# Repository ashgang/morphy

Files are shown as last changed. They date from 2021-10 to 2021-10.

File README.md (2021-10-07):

# Morphy
Contains the morphy design files and sources codes. The Hardware folder contains the schematics of various versions of the Morphy board and the associated evaluation board. The Software folder consists of the MorphyCore subfolder which contains the core morphy functionality, and the reference implementation of the client library for FreeRTOS.

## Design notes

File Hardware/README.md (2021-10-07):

# Morphy Hardware
MorphyPP3_board folder contains the design files for the Morphy PP3 form factor design.
MorphyDev_Board folder contains the design files of the development board for Morphy.

[All design documents including Board Schematics, PCB design and BOM sheets ]

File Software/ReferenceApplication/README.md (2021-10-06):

# Reference Application
This subfolder contains reference implementation of the morphy extension to FreeRTOS, the reference client library implementation is included within the freertos folder. An application example developed for Nordic nRF52840-DK board is included and the application was developed on Nordic SDK version: nRF5_SDK_17.0.2.

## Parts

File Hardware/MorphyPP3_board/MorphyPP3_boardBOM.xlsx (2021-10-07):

Comment | Description | Designator | Footprint | LibRef | Quantity
0.1uF | 0.1碌F ceramic capacitors A capacitor is a passive two-terminal electrical component used to store electrical energy temporarily in an electric field. | C1, C2, C3, C4 | 0603 | 0.1UF-0603-25V-5% | 4
C-USC0402 | CAPACITOR, American symbol | C5, C6 | C0402 | C-USC0402 | 2
FIDUCIAL1X2 | Fiducial Alignment Points Point-of-reference for pick-and-place machines and other optical instruments. | FD1, FD2, FD3, FD4 | FIDUCIAL-1X2 | FIDUCIAL1X2 | 4
AMPHENOL-BERGSTAK®-10POSPLUG | Amphenol鈥檚 BergStak庐 0.5mm is a comprehensive and versatile board-to-board solution designed for reliable and high-density applications. The unique design of scoop-proof housing ensures terminals are not damaged during mating. | J1 | 10132797-10POS-PLUG | AMPHENOL-BERGSTAK®-10POSPLUG | 1
CONN_06NO_SILK_NO_POP | Multi connection point. Often used as Generic Header-pin footprint for 0.1 inch spaced/style header connections On any of the 0.1 inch spaced packages, you can populate with these: Break Away Headers - Straight (PRT-00116) Break Away Male Headers - Right Angle (PRT-00553) Female Headers (PRT-00115) Break Away Headers - Machine Pin (PRT-00117) Break Away Female Headers - Swiss Machine Pin (PRT-00743) Arduino Stackable Header - 6 Pin (PRT-09280) For SCREWTERMINALS and SPRING TERMINALS visit here: Screw Terimnals on SparkFun.com (5mm/3.5mm/2.54mm spacing) This device is also useful as a general connection point to wire up your design to another part of your project. Our various solder wires solder well into these plated through hole pads. Hook-Up Wire - Assortment (Stranded, 22 AWG) (PRT-11375) Hook-Up Wire - Assortment (Solid Core, 22 AWG) (PRT-11367) View the entire wire category on our website here | J2 | 1X06_NO_SILK | CONN_06NO_SILK_NO_POP | 1
IIOT |  | LOGO1, LOGO2 | IIOT | IIOT | 2
PIC18(L)F65/66K40MR | 64-Pin, Low-Power, High-Performance Microcontrollers with XLP Technology | MCU1 | QFN50P900X900X100-65T715N | PIC18(L)F65/66K40MR | 1
310mA/60V/1.6Ω | N-channel MOSFETs Voltage controlled devices that allow control of high current outputs. SparkFun Products: | Q1, Q2 | SOT323 | MOSFET-NCH-2N7002PW | 2
R-EU_R0402 | RESISTOR, European symbol | R1, R2, R3, R4, R5, R6 | R0402 | R-EU_R0402 | 6
R-US_R0805 | RESISTOR, American symbol | R7 | R0805 | R-US_R0805 | 1
AB1805 |  | RTC1 | QFN-16-3X3 | AB1805 | 1
PM-5R0H/V104-R-VER | CAP 100MF -20% +80% 5V T/H | SC1, SC2, SC3, SC4, SC5, SC6, SC7, SC8, SC9, SC10, SC11, SC12, SC13, SC14, SC15, SC16 | EATON-13X11.3X6-V | PM-5R0H/V104-R-VER | 16
TEST-POINT3X4 | SparkFun Test Points Bare copper test points for troubleshooting or In-Circuit-Testing. These are used by our Production team for verifying production board runs using pogo-pins on test beds. SparkFun Products: SparkFun Load Cell Amplifier | TP1, TP2, TP3 | PAD.03X.04 | TEST-POINT3X4 | 3
ADG824 | 0.5 鈩?CMOS 1.65 V to 3.6 V Dual SPDT/2:1 Mux in Mini LFCSP Package | U1, U2, U3, U4, U5, U6, U7, U8, U9, U10, U11, U12, U13, U14, U15, U16, U17 | CP-10-10 | ADG824 | 17

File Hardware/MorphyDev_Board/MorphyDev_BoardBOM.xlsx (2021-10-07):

Comment | Description | Designator | Footprint | LibRef | Quantity
BAT-1CELLKEYSTONE-1058 |  | BAT1 | KEYSTONE-1058 | BAT-1CELLKEYSTONE-1058 | 1
0.1uF | CAPACITOR, American symbol | C1, C2, C3, C4 | C0603 | C-USC0603 | 4
C-USC0603 | CAPACITOR, American symbol | C5, C6 | C0603 | C-USC0603 | 2
CONN_02 | Multi connection point. Often used as Generic Header-pin footprint for 0.1 inch spaced/style header connections On any of the 0.1 inch spaced packages, you can populate with these: Break Away Headers - Straight (PRT-00116) Break Away Male Headers - Right Angle (PRT-00553) Female Headers (PRT-00115) Break Away Headers - Machine Pin (PRT-00117) Break Away Female Headers - Swiss Machine Pin (PRT-00743) For SCREWTERMINALS and SPRING TERMINALS visit here: Screw Terimnals on SparkFun.com (5mm/3.5mm/2.54mm spacing) This device is also useful as a general connection point to wire up your design to another part of your project. Our various solder wires solder well into these plated through hole pads. Hook-Up Wire - Assortment (Stranded, 22 AWG) (PRT-11375) Hook-Up Wire - Assortment (Solid Core, 22 AWG) (PRT-11367) View the entire wire category on our website here Special notes: Molex polarized connector foot print use with: PRT-08233 with associated crimp pins and housings. 2.54_SCREWTERM for use with PRT-10571. 3.5mm Screw Terminal footprints for PRT-08084 5mm Screw Terminal footprints for use with PRT-08432 | J1 | 1X02 | CONN_02 | 1
CONN_06NO_SILK_NO_POP | Multi connection point. Often used as Generic Header-pin footprint for 0.1 inch spaced/style header connections On any of the 0.1 inch spaced packages, you can populate with these: Break Away Headers - Straight (PRT-00116) Break Away Male Headers - Right Angle (PRT-00553) Female Headers (PRT-00115) Break Away Headers - Machine Pin (PRT-00117) Break Away Female Headers - Swiss Machine Pin (PRT-00743) Arduino Stackable Header - 6 Pin (PRT-09280) For SCREWTERMINALS and SPRING TERMINALS visit here: Screw Terimnals on SparkFun.com (5mm/3.5mm/2.54mm spacing) This device is also useful as a general connection point to wire up your design to another part of your project. Our various solder wires solder well into these plated through hole pads. Hook-Up Wire - Assortment (Stranded, 22 AWG) (PRT-11375) Hook-Up Wire - Assortment (Solid Core, 22 AWG) (PRT-11367) View the entire wire category on our website here | J2 | 1X06_NO_SILK | CONN_06NO_SILK_NO_POP | 1
CONN_025MM | Multi connection point. Often used as Generic Header-pin footprint for 0.1 inch spaced/style header connections On any of the 0.1 inch spaced packages, you can populate with these: Break Away Headers - Straight (PRT-00116) Break Away Male Headers - Right Angle (PRT-00553) Female Headers (PRT-00115) Break Away Headers - Machine Pin (PRT-00117) Break Away Female Headers - Swiss Machine Pin (PRT-00743) For SCREWTERMINALS and SPRING TERMINALS visit here: Screw Terimnals on SparkFun.com (5mm/3.5mm/2.54mm spacing) This device is also useful as a general connection point to wire up your design to another part of your project. Our various solder wires solder well into these plated through hole pads. Hook-Up Wire - Assortment (Stranded, 22 AWG) (PRT-11375) Hook-Up Wire - Assortment (Solid Core, 22 AWG) (PRT-11367) View the entire wire category on our website here Special notes: Molex polarized connector foot print use with: PRT-08233 with associated crimp pins and housings. 2.54_SCREWTERM for use with PRT-10571. 3.5mm Screw Terminal footprints for PRT-08084 5mm Screw Terminal footprints for use with PRT-08432 | J3, J4 | SCREWTERMINAL-5MM-2 | CONN_025MM | 2
CONN_03 | Multi connection point. Often used as Generic Header-pin footprint for 0.1 inch spaced/style header connections On any of the 0.1 inch spaced packages, you can populate with these: Break Away Headers - Straight (PRT-00116) Break Away Male Headers - Right Angle (PRT-00553) Female Headers (PRT-00115) Break Away Headers - Machine Pin (PRT-00117) Break Away Female Headers - Swiss Machine Pin (PRT-00743) Stackable Header - 3 Pin (Female, 0.1") (PRT-13875) For SCREWTERMINALS and SPRING TERMINALS visit here: Screw Terimnals on SparkFun.com (5mm/3.5mm/2.54mm spacing) This device is also useful as a general connection point to wire up your design to another part of your project. Our various solder wires solder well into these plated through hole pads. Hook-Up Wire - Assortment (Stranded, 22 AWG) (PRT-11375) Hook-Up Wire - Assortment (Solid Core, 22 AWG) (PRT-11367) View the entire wire category on our website here Special notes: Molex polarized connector foot print use with SKU : PRT-08232 with associated crimp pins and housings. | J5 | 1X03 | CONN_03 | 1
PIC18(L)F65/66K40PT | 64-Pin, Low-Power, High-Performance Microcontrollers with XLP Technology | MCU1 | QFP50P1200X1200X120-64N | PIC18(L)F65/66K40PT | 1
310mA/60V/1.6Ω | N-channel MOSFETs Voltage controlled devices that allow control of high current outputs. SparkFun Products: | Q1, Q2 | SOT323 | MOSFET-NCH-2N7002PW | 2
R-US_R0603 | RESISTOR, American symbol | R1, R2, R3, R4, R5, R6, R8, R9 | R0603 | R-US_R0603 | 8
R-US_R0805 | RESISTOR, American symbol | R7 | R0805 | R-US_R0805 | 1
AB1805 |  | RTC1 | QFN-16-3X3 | AB1805 | 1
PM-5R0H/V104-R-VER | CAP 100MF -20% +80% 5V T/H | SC1, SC2, SC3, SC4, SC5, SC6, SC7, SC8, SC9, SC10, SC11, SC12, SC13, SC14, SC15, SC16 | EATON-13X11.3X6-V | PM-5R0H/V104-R-VER | 16
TEST-POINT3X4 | SparkFun Test Points Bare copper test points for troubleshooting or In-Circuit-Testing. These are used by our Production team for verifying production board runs using pogo-pins on test beds. SparkFun Products: SparkFun Load Cell Amplifier | TP1, TP3 | PAD.03X.04 | TEST-POINT3X4 | 2
DG2535EDQ | IC ANALOG SWITCH DUAL | U1, U2, U3, U4, U5, U6, U7, U8, U9, U10, U11, U12, U13, U14, U15, U16, U17 | SOP50P490X110-10N | DG2535EDQ | 17

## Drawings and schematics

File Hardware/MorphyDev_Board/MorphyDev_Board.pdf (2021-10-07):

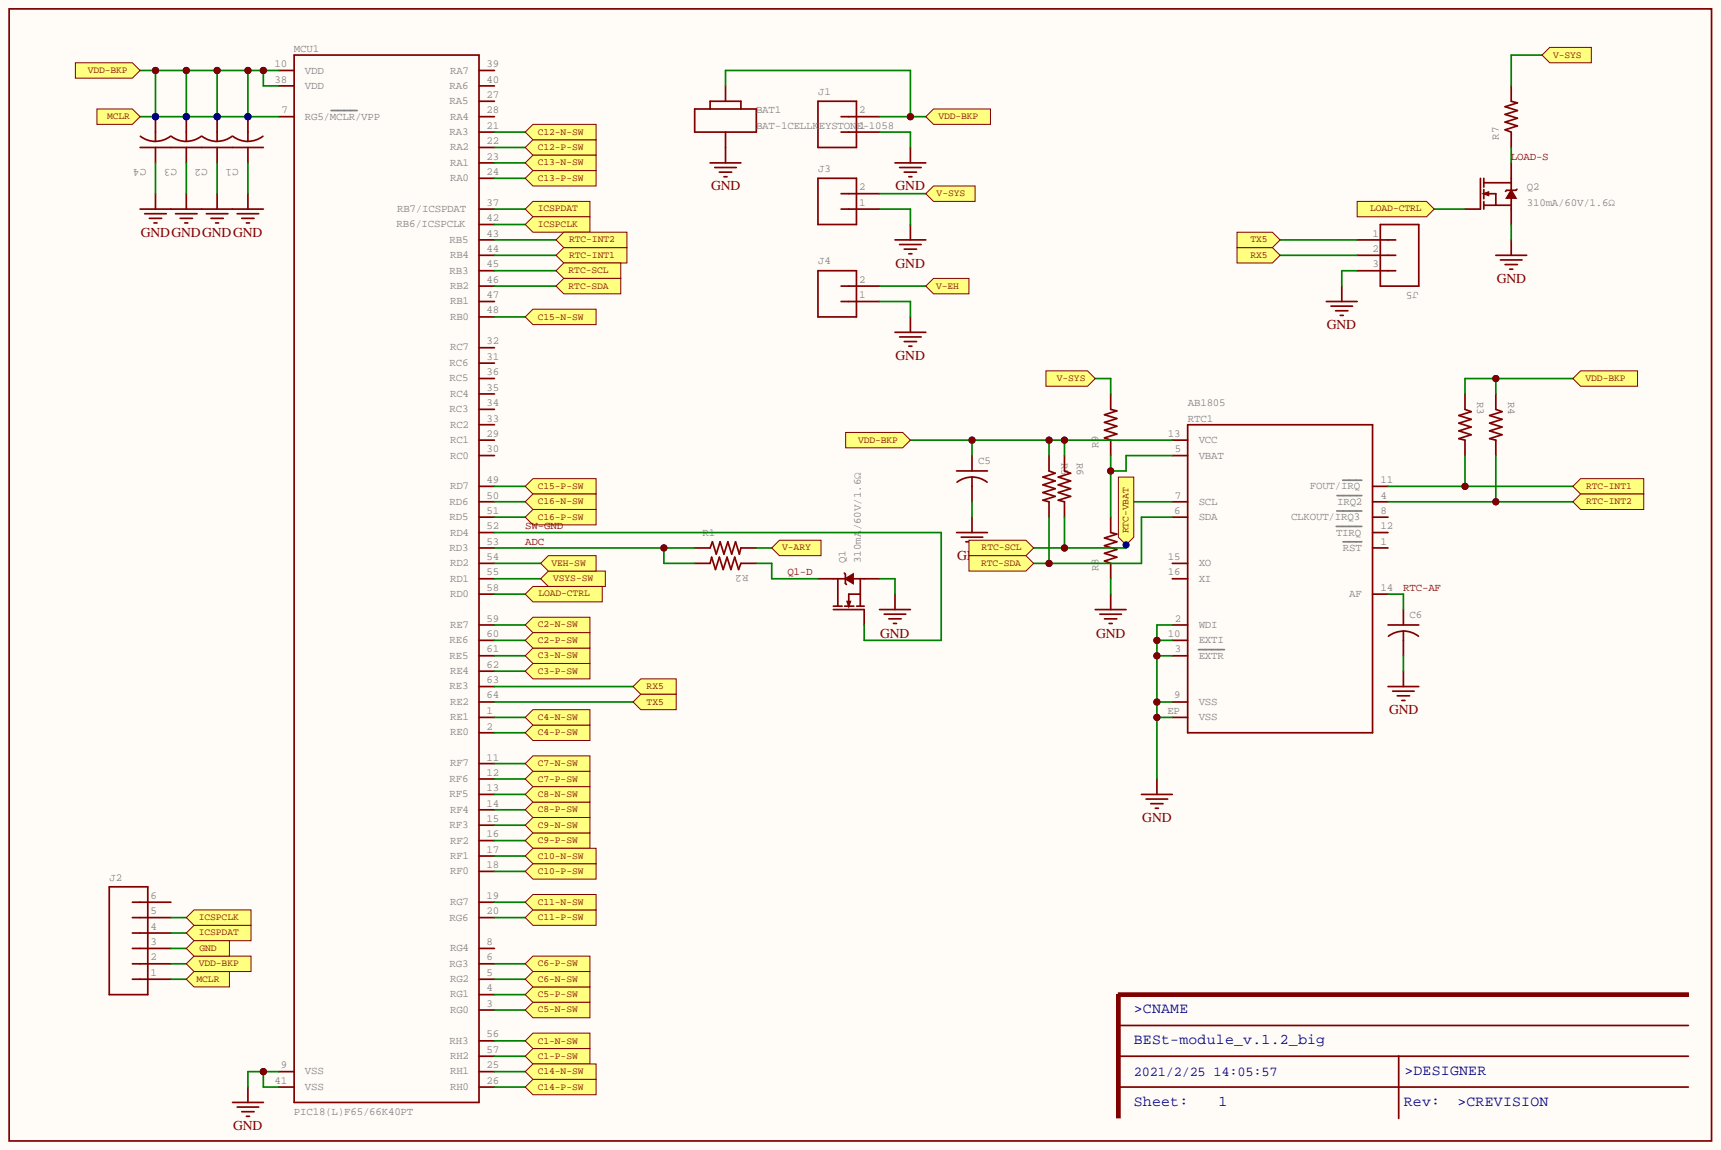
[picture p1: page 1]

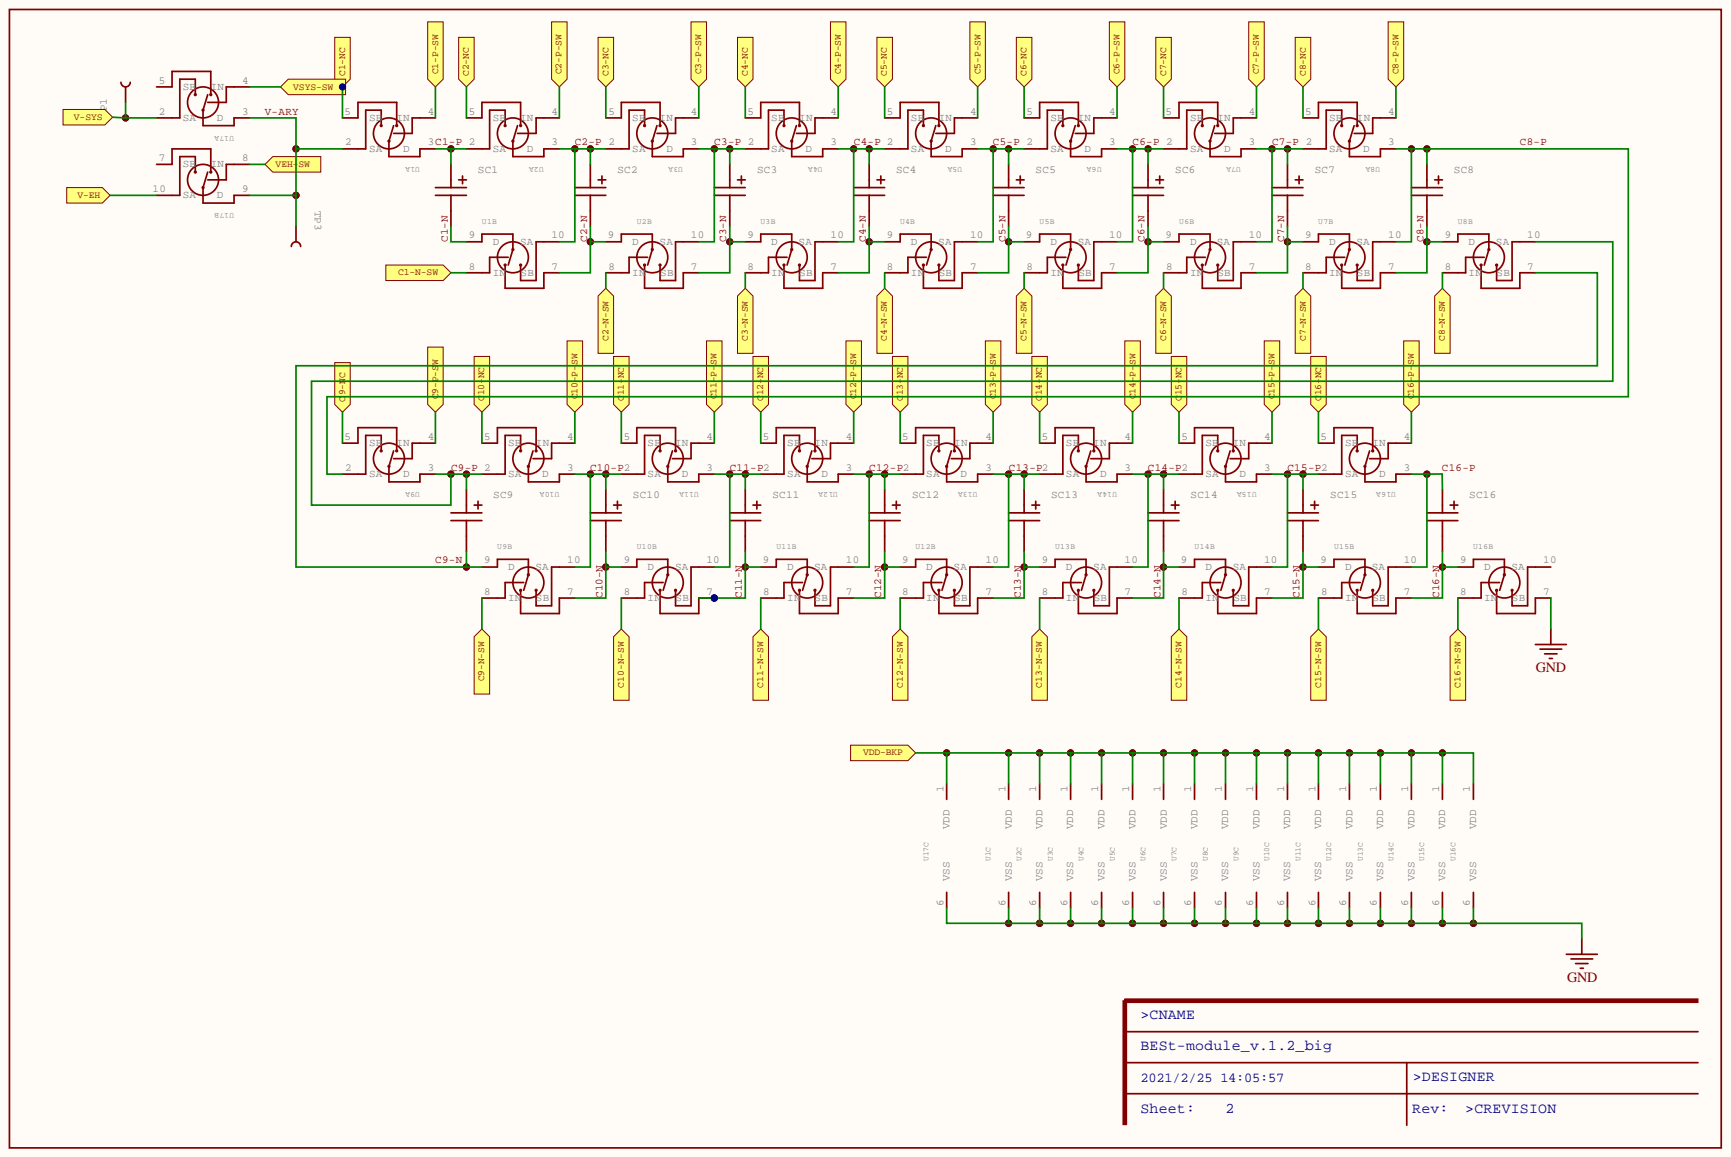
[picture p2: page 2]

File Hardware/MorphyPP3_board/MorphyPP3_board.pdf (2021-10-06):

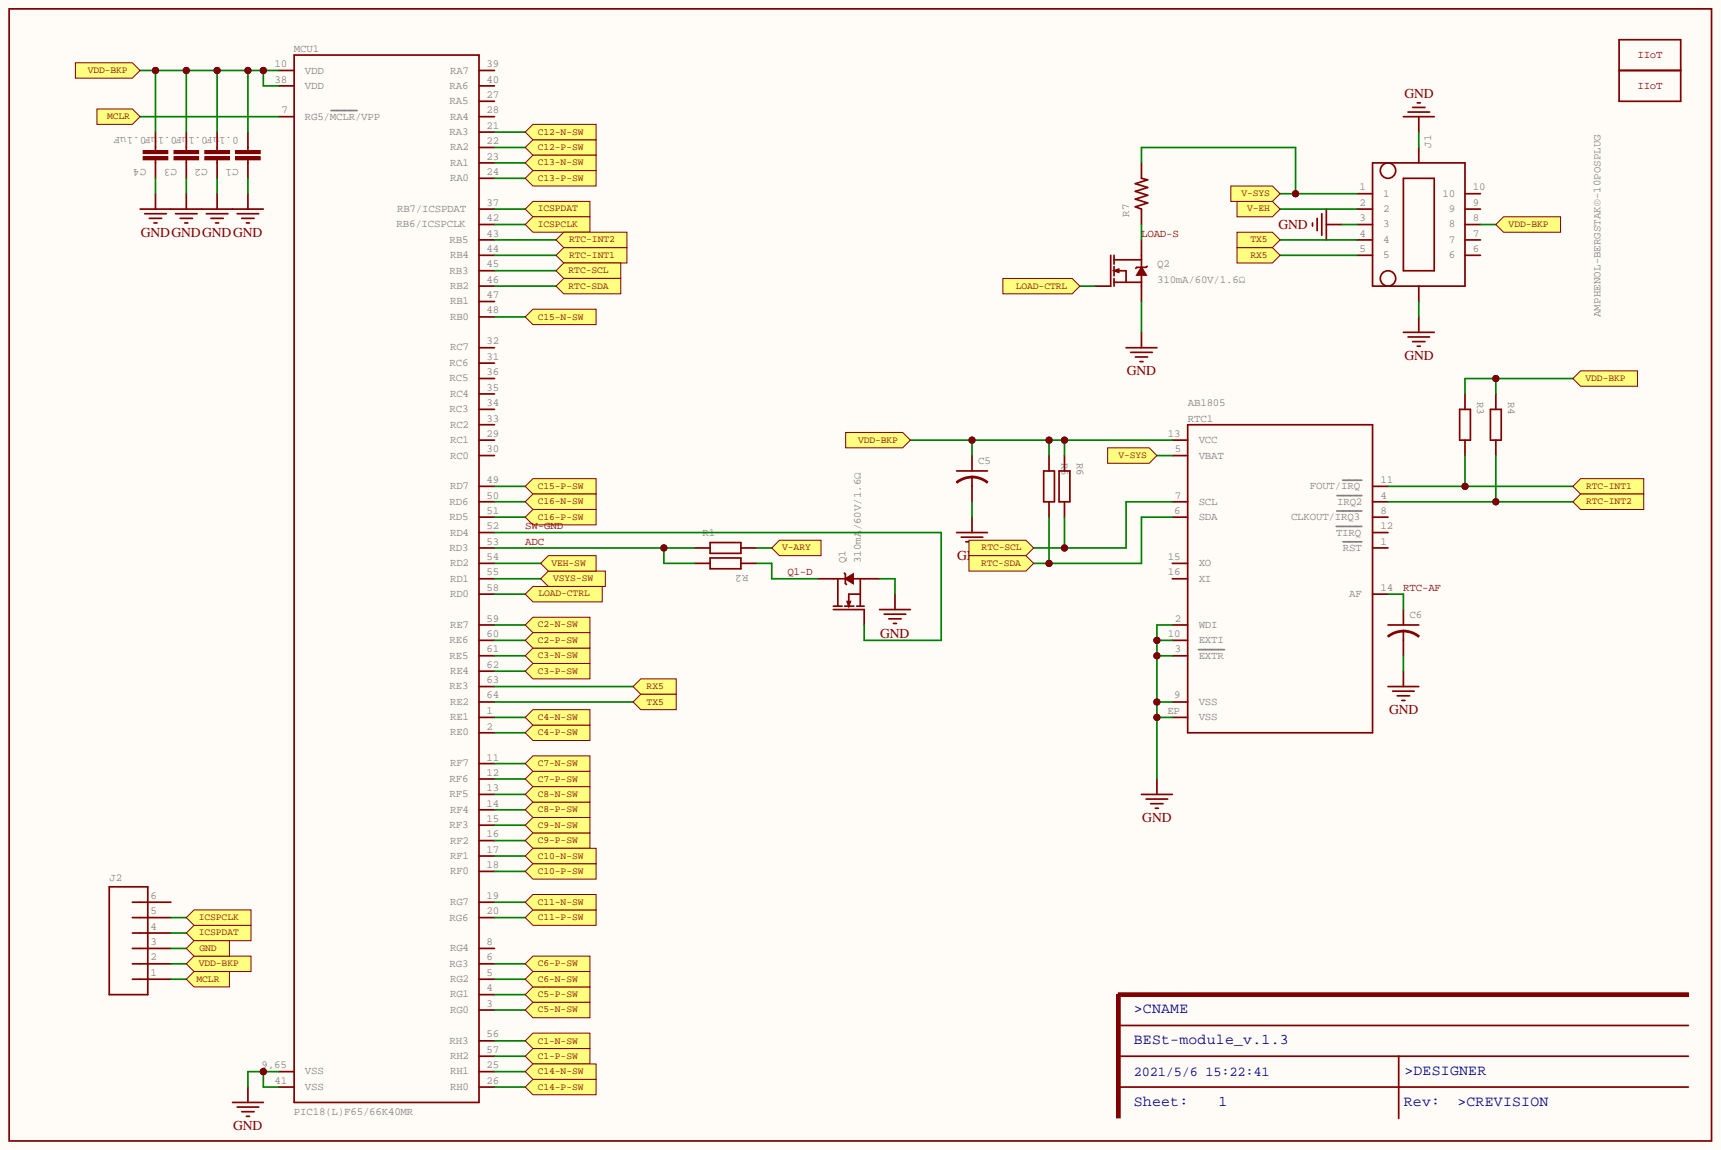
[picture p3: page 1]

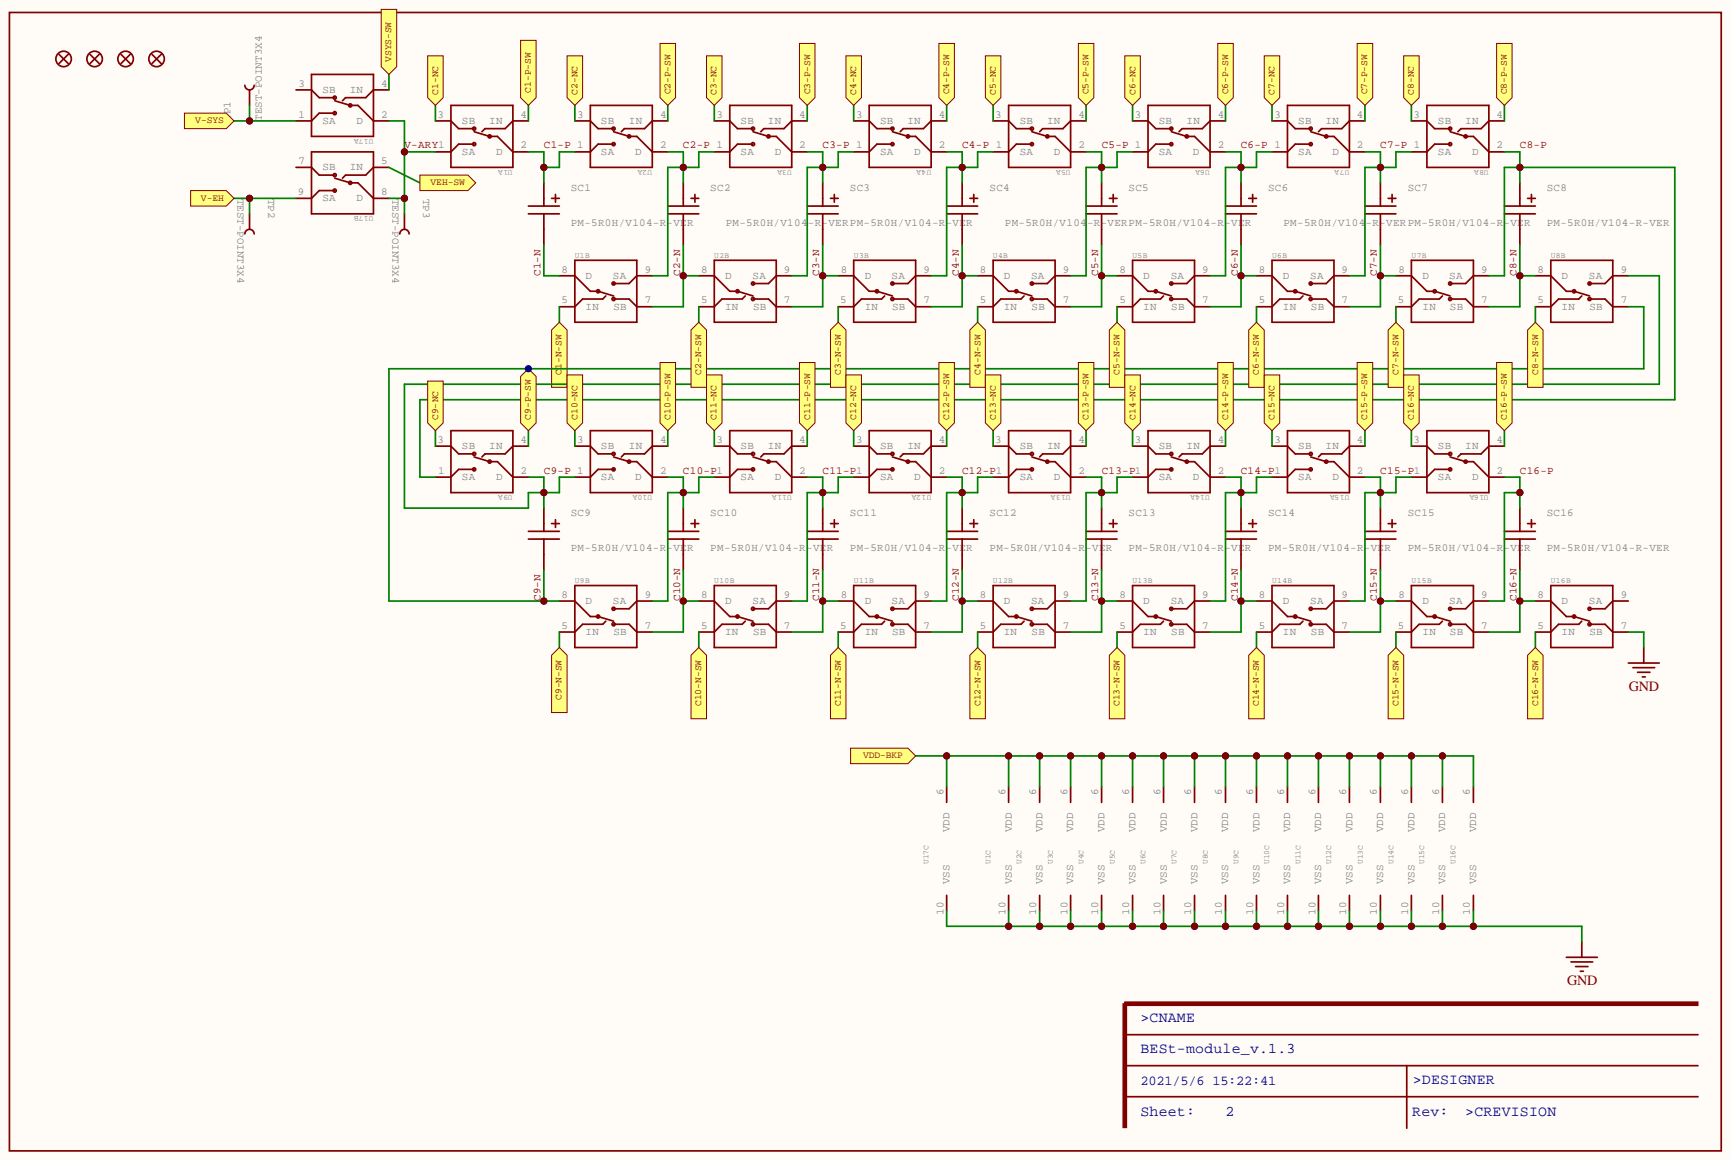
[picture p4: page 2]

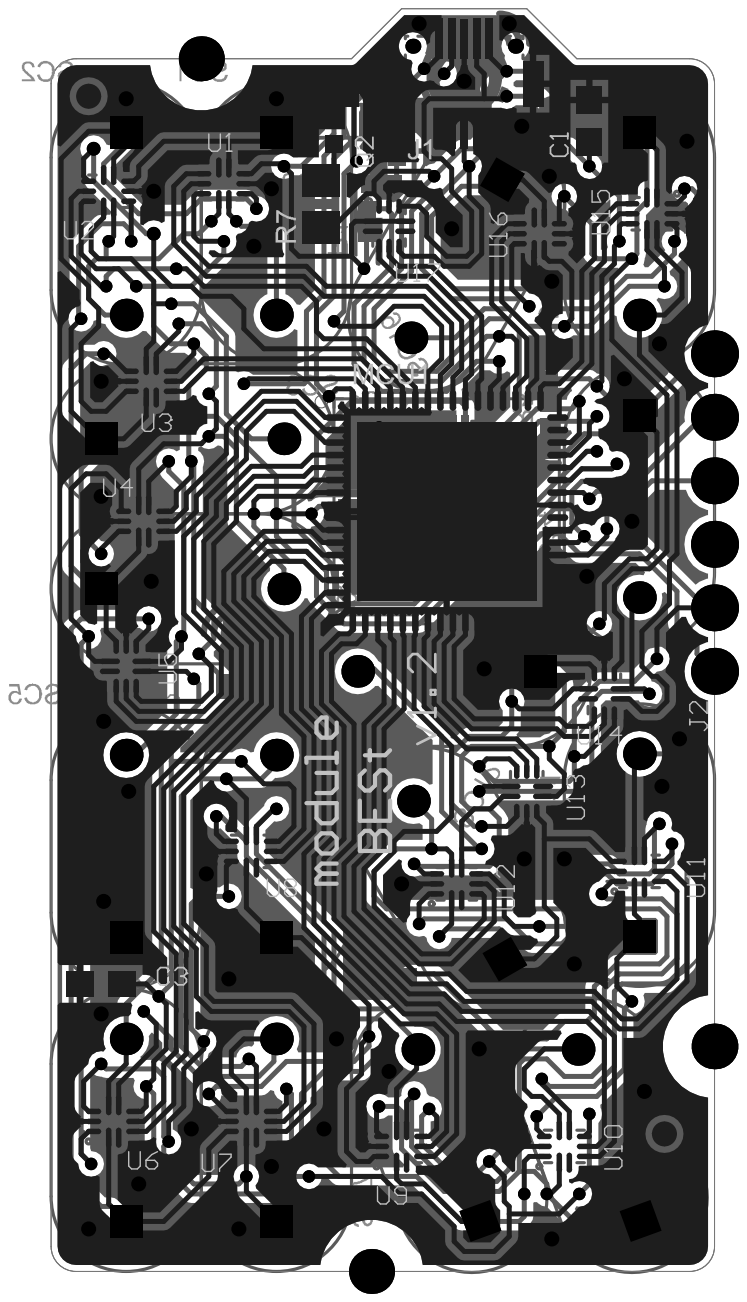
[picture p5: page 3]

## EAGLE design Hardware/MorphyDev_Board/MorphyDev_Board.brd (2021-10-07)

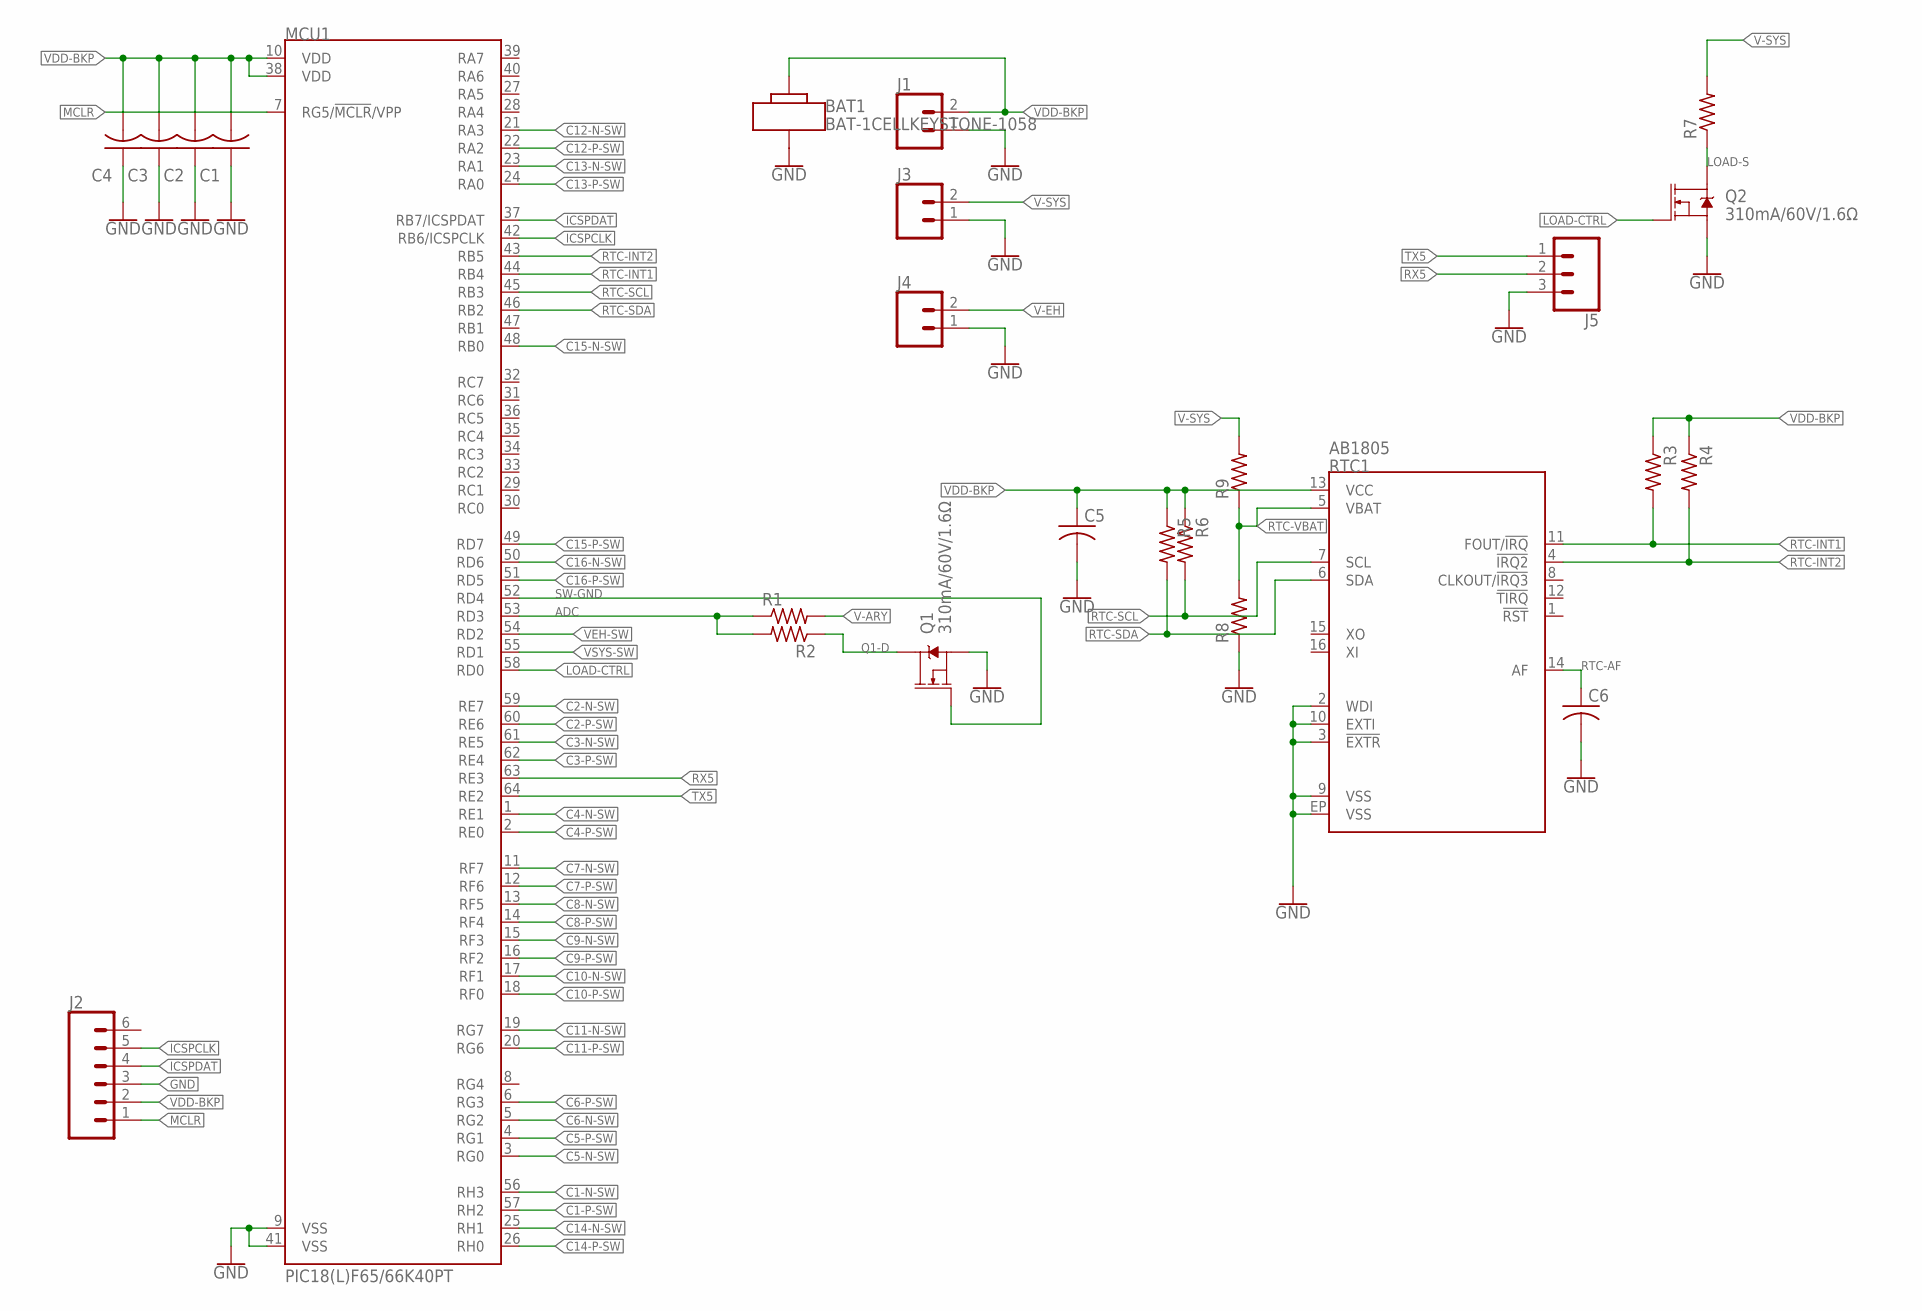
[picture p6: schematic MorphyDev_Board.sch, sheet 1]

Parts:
BAT1: BAT-1CELLKEYSTONE-1058; KEYSTONE-1058
C1, C2, C3, C4: 0.1uF; C0603
C5, C6: C-USC0603; C0603
J1: CONN_02; 1X02
J2: CONN_06NO_SILK_NO_POP; 1X06_NO_SILK
J3, J4: CONN_025MM; SCREWTERMINAL-5MM-2
J5: CONN_03; 1X03
MCU1: PIC18(L)F65/66K40PT; QFP50P1200X1200X120-64N
Q1, Q2: 310mA/60V/1.6Ω; SOT323
R1, R2, R3, R4, R5, R6, R8, R9: R-US_R0603; R0603
R7: R-US_R0805; R0805
RTC1: AB1805; QFN-16-3X3

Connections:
ADC: MCU1.53 (RD3), R1.1, R2.2
C1-N-SW: MCU1.56 (RH3); also elsewhere on the board
C1-P-SW: MCU1.57 (RH2); also elsewhere on the board
C2-N-SW: MCU1.59 (RE7); also elsewhere on the board
C2-P-SW: MCU1.60 (RE6); also elsewhere on the board
C3-N-SW: MCU1.61 (RE5); also elsewhere on the board
C3-P-SW: MCU1.62 (RE4); also elsewhere on the board
C4-N-SW: MCU1.1 (RE1); also elsewhere on the board
C4-P-SW: MCU1.2 (RE0); also elsewhere on the board
C5-N-SW: MCU1.3 (RG0); also elsewhere on the board
C5-P-SW: MCU1.4 (RG1); also elsewhere on the board
C6-N-SW: MCU1.5 (RG2); also elsewhere on the board
C6-P-SW: MCU1.6 (RG3); also elsewhere on the board
C7-N-SW: MCU1.11 (RF7); also elsewhere on the board
C7-P-SW: MCU1.12 (RF6); also elsewhere on the board
C8-N-SW: MCU1.13 (RF5); also elsewhere on the board
C8-P-SW: MCU1.14 (RF4); also elsewhere on the board
C9-N-SW: MCU1.15 (RF3); also elsewhere on the board
C9-P-SW: MCU1.16 (RF2); also elsewhere on the board
C10-N-SW: MCU1.17 (RF1); also elsewhere on the board
C10-P-SW: MCU1.18 (RF0); also elsewhere on the board
C11-N-SW: MCU1.19 (RG7); also elsewhere on the board
C11-P-SW: MCU1.20 (RG6); also elsewhere on the board
C12-N-SW: MCU1.21 (RA3); also elsewhere on the board
C12-P-SW: MCU1.22 (RA2); also elsewhere on the board
C13-N-SW: MCU1.23 (RA1); also elsewhere on the board
C13-P-SW: MCU1.24 (RA0); also elsewhere on the board
C14-N-SW: MCU1.25 (RH1); also elsewhere on the board
C14-P-SW: MCU1.26 (RH0); also elsewhere on the board
C15-N-SW: MCU1.48 (RB0); also elsewhere on the board
C15-P-SW: MCU1.49 (RD7); also elsewhere on the board
C16-N-SW: MCU1.50 (RD6); also elsewhere on the board
C16-P-SW: MCU1.51 (RD5); also elsewhere on the board
GND: BAT1.N, C1.1, C2.1, C3.1, C4.1, C5.2, C6.2, J1.1, J2.3, J3.1, J4.1, J5.3, MCU1.9 (VSS), MCU1.41 (VSS), Q1.2 (S), Q2.2 (S), R8.1, RTC1.2 (WDI), RTC1.3 (!EXTR), RTC1.9 (VSS), RTC1.10 (EXTI), RTC1.EP (VSS); also elsewhere on the board
ICSPCLK: J2.5, MCU1.42 (RB6/ICSPCLK)
ICSPDAT: J2.4, MCU1.37 (RB7/ICSPDAT)
LOAD-CTRL: MCU1.58 (RD0), Q2.1 (G)
LOAD-S: Q2.3 (D), R7.1
MCLR: J2.1, MCU1.7 (RG5/!MCLR!/VPP)
Q1-D: Q1.3 (D), R2.1
RTC-AF: C6.1, RTC1.14 (AF)
RTC-INT1: MCU1.44 (RB4), R3.2, RTC1.11 (FOUT/!IRQ)
RTC-INT2: MCU1.43 (RB5), R4.2, RTC1.4 (!IRQ2)
RTC-SCL: MCU1.45 (RB3), R6.2, RTC1.7 (SCL)
RTC-SDA: MCU1.46 (RB2), R5.2, RTC1.6 (SDA)
RTC-VBAT: R8.2, R9.1, RTC1.5 (VBAT)
RX5: J5.2, MCU1.63 (RE3)
SW-GND: MCU1.52 (RD4), Q1.1 (G)
TX5: J5.1, MCU1.64 (RE2)
V-ARY: R1.2; also elsewhere on the board
V-EH: J4.2; also elsewhere on the board
V-SYS: J3.2, R7.2, R9.2; also elsewhere on the board
VDD-BKP: BAT1.P, C1.2, C2.2, C3.2, C4.2, C5.1, J1.2, J2.2, MCU1.10 (VDD), MCU1.38 (VDD), R3.1, R4.1, R5.1, R6.1, RTC1.13 (VCC); also elsewhere on the board
VEH-SW: MCU1.54 (RD2); also elsewhere on the board
VSYS-SW: MCU1.55 (RD1); also elsewhere on the board

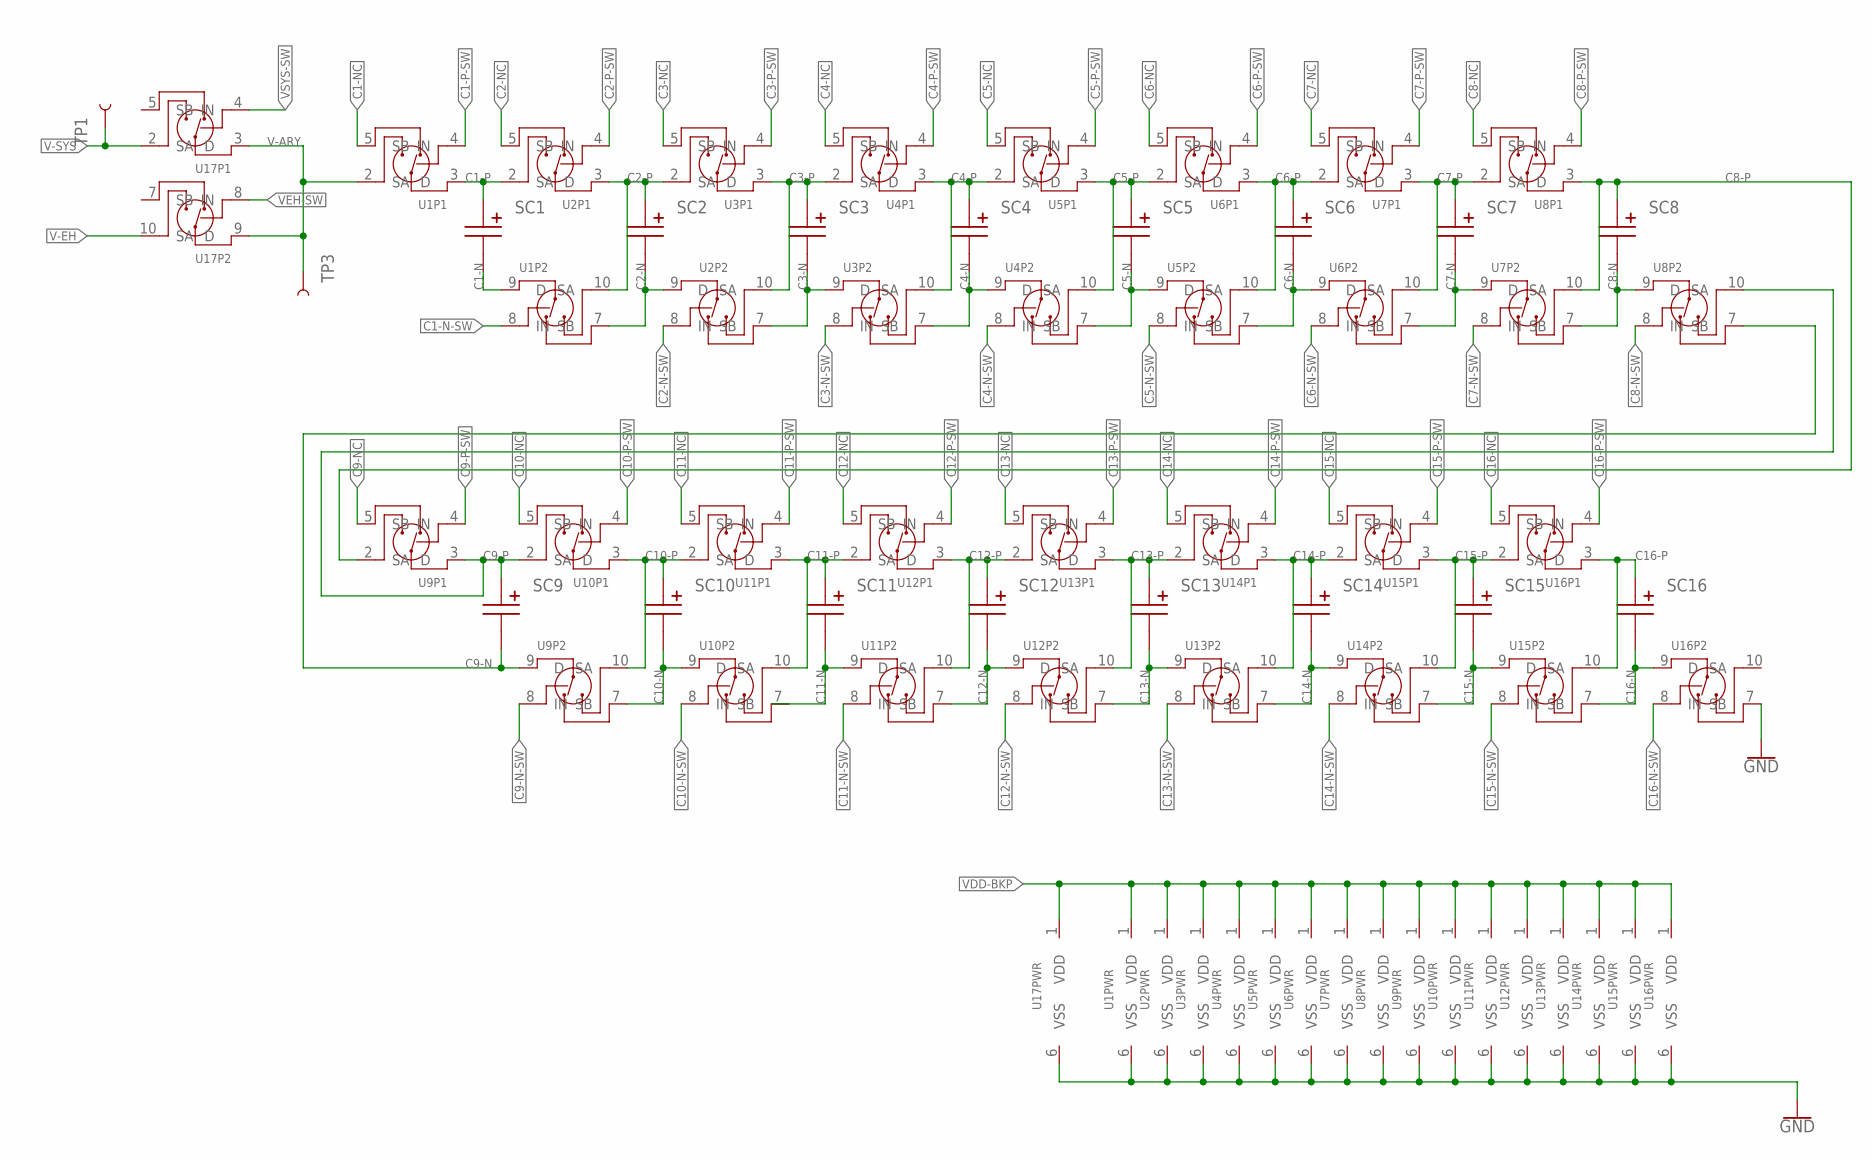
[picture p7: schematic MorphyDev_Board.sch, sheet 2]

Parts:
SC1, SC2, SC3, SC4, SC5, SC6, SC7, SC8, SC9, SC10, SC11, SC12, SC13, SC14, SC15, SC16: PM-5R0H/V104-R-VER; EATON-13X11.3X6-V
TP1, TP3: TEST-POINT3X4; PAD.03X.04
U1, U2, U3, U4, U5, U6, U7, U8, U9, U10, U11, U12, U13, U14, U15, U16, U17: DG2535EDQ; SOP50P490X110-10N

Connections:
C1-N: SC1.N, U1.9 (D)
C1-N-SW: U1.8 (IN); also elsewhere on the board
C1-NC: U1.5 (SB)
C1-P: SC1.P, U1.3 (D), U2.2 (SA)
C1-P-SW: U1.4 (IN); also elsewhere on the board
C2-N: SC2.N, U1.7 (SB), U2.9 (D)
C2-N-SW: U2.8 (IN); also elsewhere on the board
C2-NC: U2.5 (SB)
C2-P: SC2.P, U1.10 (SA), U2.3 (D), U3.2 (SA)
C2-P-SW: U2.4 (IN); also elsewhere on the board
C3-N: SC3.N, U2.7 (SB), U3.9 (D)
C3-N-SW: U3.8 (IN); also elsewhere on the board
C3-NC: U3.5 (SB)
C3-P: SC3.P, U2.10 (SA), U3.3 (D), U4.2 (SA)
C3-P-SW: U3.4 (IN); also elsewhere on the board
C4-N: SC4.N, U3.7 (SB), U4.9 (D)
C4-N-SW: U4.8 (IN); also elsewhere on the board
C4-NC: U4.5 (SB)
C4-P: SC4.P, U3.10 (SA), U4.3 (D), U5.2 (SA)
C4-P-SW: U4.4 (IN); also elsewhere on the board
C5-N: SC5.N, U4.7 (SB), U5.9 (D)
C5-N-SW: U5.8 (IN); also elsewhere on the board
C5-NC: U5.5 (SB)
C5-P: SC5.P, U4.10 (SA), U5.3 (D), U6.2 (SA)
C5-P-SW: U5.4 (IN); also elsewhere on the board
C6-N: SC6.N, U5.7 (SB), U6.9 (D)
C6-N-SW: U6.8 (IN); also elsewhere on the board
C6-NC: U6.5 (SB)
C6-P: SC6.P, U5.10 (SA), U6.3 (D), U7.2 (SA)
C6-P-SW: U6.4 (IN); also elsewhere on the board
C7-N: SC7.N, U6.7 (SB), U7.9 (D)
C7-N-SW: U7.8 (IN); also elsewhere on the board
C7-NC: U7.5 (SB)
C7-P: SC7.P, U6.10 (SA), U7.3 (D), U8.2 (SA)
C7-P-SW: U7.4 (IN); also elsewhere on the board
C8-N: SC8.N, U7.7 (SB), U8.9 (D)
C8-N-SW: U8.8 (IN); also elsewhere on the board
C8-NC: U8.5 (SB)
C8-P: SC8.P, U7.10 (SA), U8.3 (D), U9.2 (SA)
C8-P-SW: U8.4 (IN); also elsewhere on the board
C9-N: SC9.N, U8.7 (SB), U9.9 (D)
C9-N-SW: U9.8 (IN); also elsewhere on the board
C9-NC: U9.5 (SB)
C9-P: SC9.P, U8.10 (SA), U9.3 (D), U10.2 (SA)
C9-P-SW: U9.4 (IN); also elsewhere on the board
C10-N: SC10.N, U9.7 (SB), U10.9 (D)
C10-N-SW: U10.8 (IN); also elsewhere on the board
C10-NC: U10.5 (SB)
C10-P: SC10.P, U9.10 (SA), U10.3 (D), U11.2 (SA)
C10-P-SW: U10.4 (IN); also elsewhere on the board
C11-N: SC11.N, U10.7 (SB), U11.9 (D)
C11-N-SW: U11.8 (IN); also elsewhere on the board
C11-NC: U11.5 (SB)
C11-P: SC11.P, U10.10 (SA), U11.3 (D), U12.2 (SA)
C11-P-SW: U11.4 (IN); also elsewhere on the board
C12-N: SC12.N, U11.7 (SB), U12.9 (D)
C12-N-SW: U12.8 (IN); also elsewhere on the board
C12-NC: U12.5 (SB)
C12-P: SC12.P, U11.10 (SA), U12.3 (D), U13.2 (SA)
C12-P-SW: U12.4 (IN); also elsewhere on the board
C13-N: SC13.N, U12.7 (SB), U13.9 (D)
C13-N-SW: U13.8 (IN); also elsewhere on the board
C13-NC: U13.5 (SB)
C13-P: SC13.P, U12.10 (SA), U13.3 (D), U14.2 (SA)
C13-P-SW: U13.4 (IN); also elsewhere on the board
C14-N: SC14.N, U13.7 (SB), U14.9 (D)
C14-N-SW: U14.8 (IN); also elsewhere on the board
C14-NC: U14.5 (SB)
C14-P: SC14.P, U13.10 (SA), U14.3 (D), U15.2 (SA)
C14-P-SW: U14.4 (IN); also elsewhere on the board
C15-N: SC15.N, U14.7 (SB), U15.9 (D)
C15-N-SW: U15.8 (IN); also elsewhere on the board
C15-NC: U15.5 (SB)
C15-P: SC15.P, U14.10 (SA), U15.3 (D), U16.2 (SA)
C15-P-SW: U15.4 (IN); also elsewhere on the board
C16-N: SC16.N, U15.7 (SB), U16.9 (D)
C16-N-SW: U16.8 (IN); also elsewhere on the board
C16-NC: U16.5 (SB)
C16-P: SC16.P, U15.10 (SA), U16.3 (D)
C16-P-SW: U16.4 (IN); also elsewhere on the board
GND: U1.6 (VSS), U2.6 (VSS), U3.6 (VSS), U4.6 (VSS), U5.6 (VSS), U6.6 (VSS), U7.6 (VSS), U8.6 (VSS), U9.6 (VSS), U10.6 (VSS), U11.6 (VSS), U12.6 (VSS), U13.6 (VSS), U14.6 (VSS), U15.6 (VSS), U16.6 (VSS), U16.7 (SB), U17.6 (VSS); also elsewhere on the board
V-ARY: TP3.P$1, U1.2 (SA), U17.3 (D), U17.9 (D); also elsewhere on the board
V-EH: U17.10 (SA); also elsewhere on the board
V-SYS: TP1.P$1, U17.2 (SA); also elsewhere on the board
VDD-BKP: U1.1 (VDD), U2.1 (VDD), U3.1 (VDD), U4.1 (VDD), U5.1 (VDD), U6.1 (VDD), U7.1 (VDD), U8.1 (VDD), U9.1 (VDD), U10.1 (VDD), U11.1 (VDD), U12.1 (VDD), U13.1 (VDD), U14.1 (VDD), U15.1 (VDD), U16.1 (VDD), U17.1 (VDD); also elsewhere on the board
VEH-SW: U17.8 (IN); also elsewhere on the board
VSYS-SW: U17.4 (IN); also elsewhere on the board

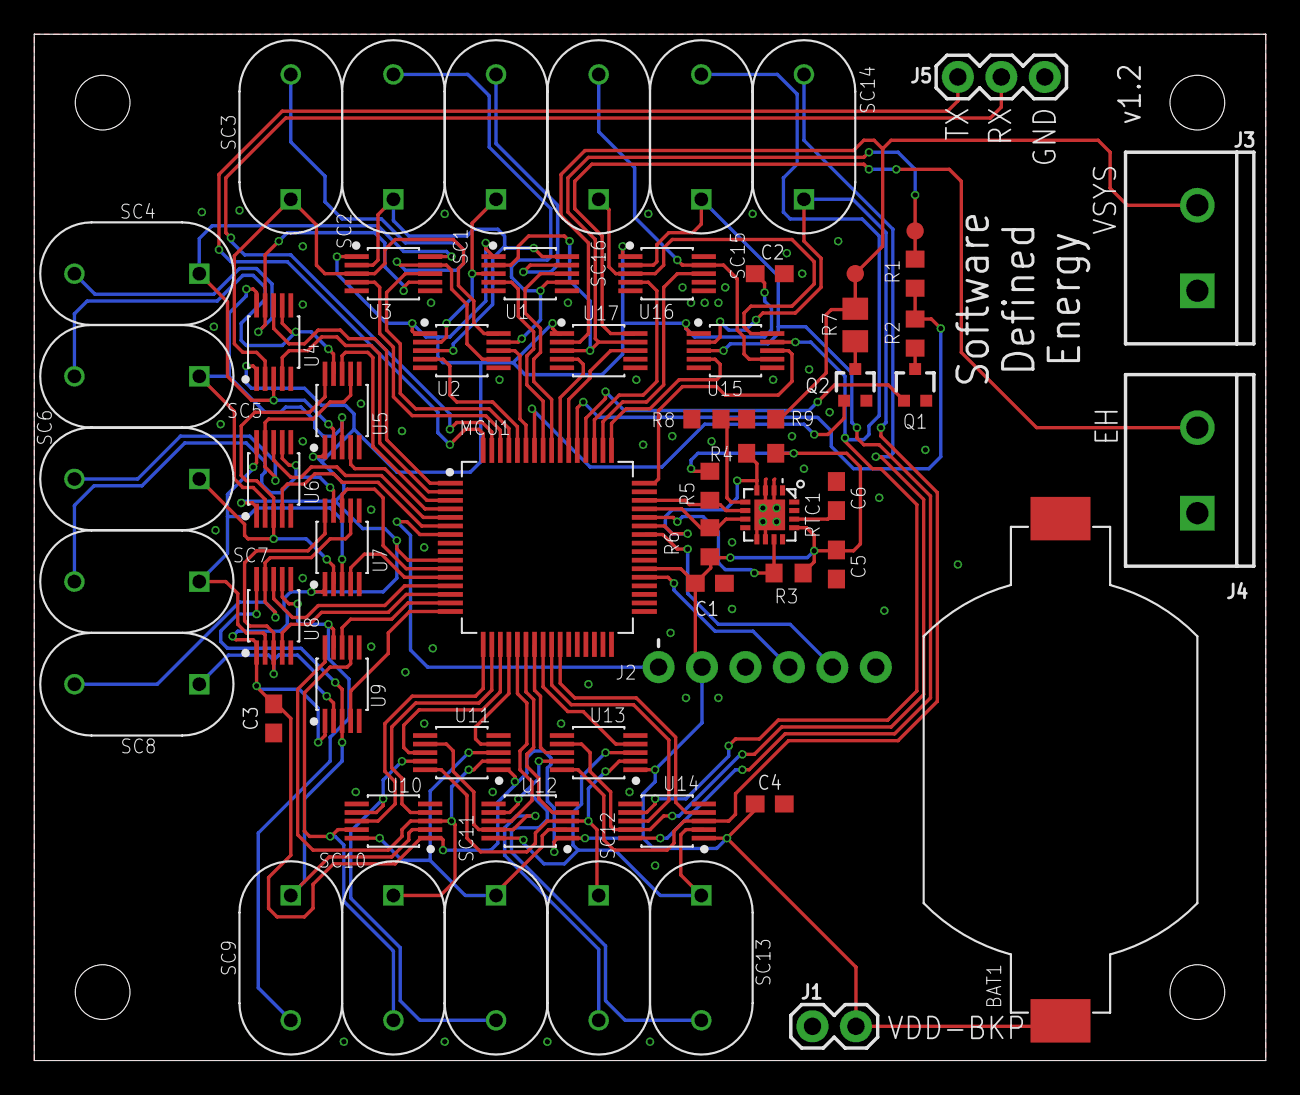
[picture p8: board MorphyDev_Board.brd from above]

Board: 2 copper layers, 72.0 x 60.0 mm, 60 parts (0 on the bottom side), 87 nets.

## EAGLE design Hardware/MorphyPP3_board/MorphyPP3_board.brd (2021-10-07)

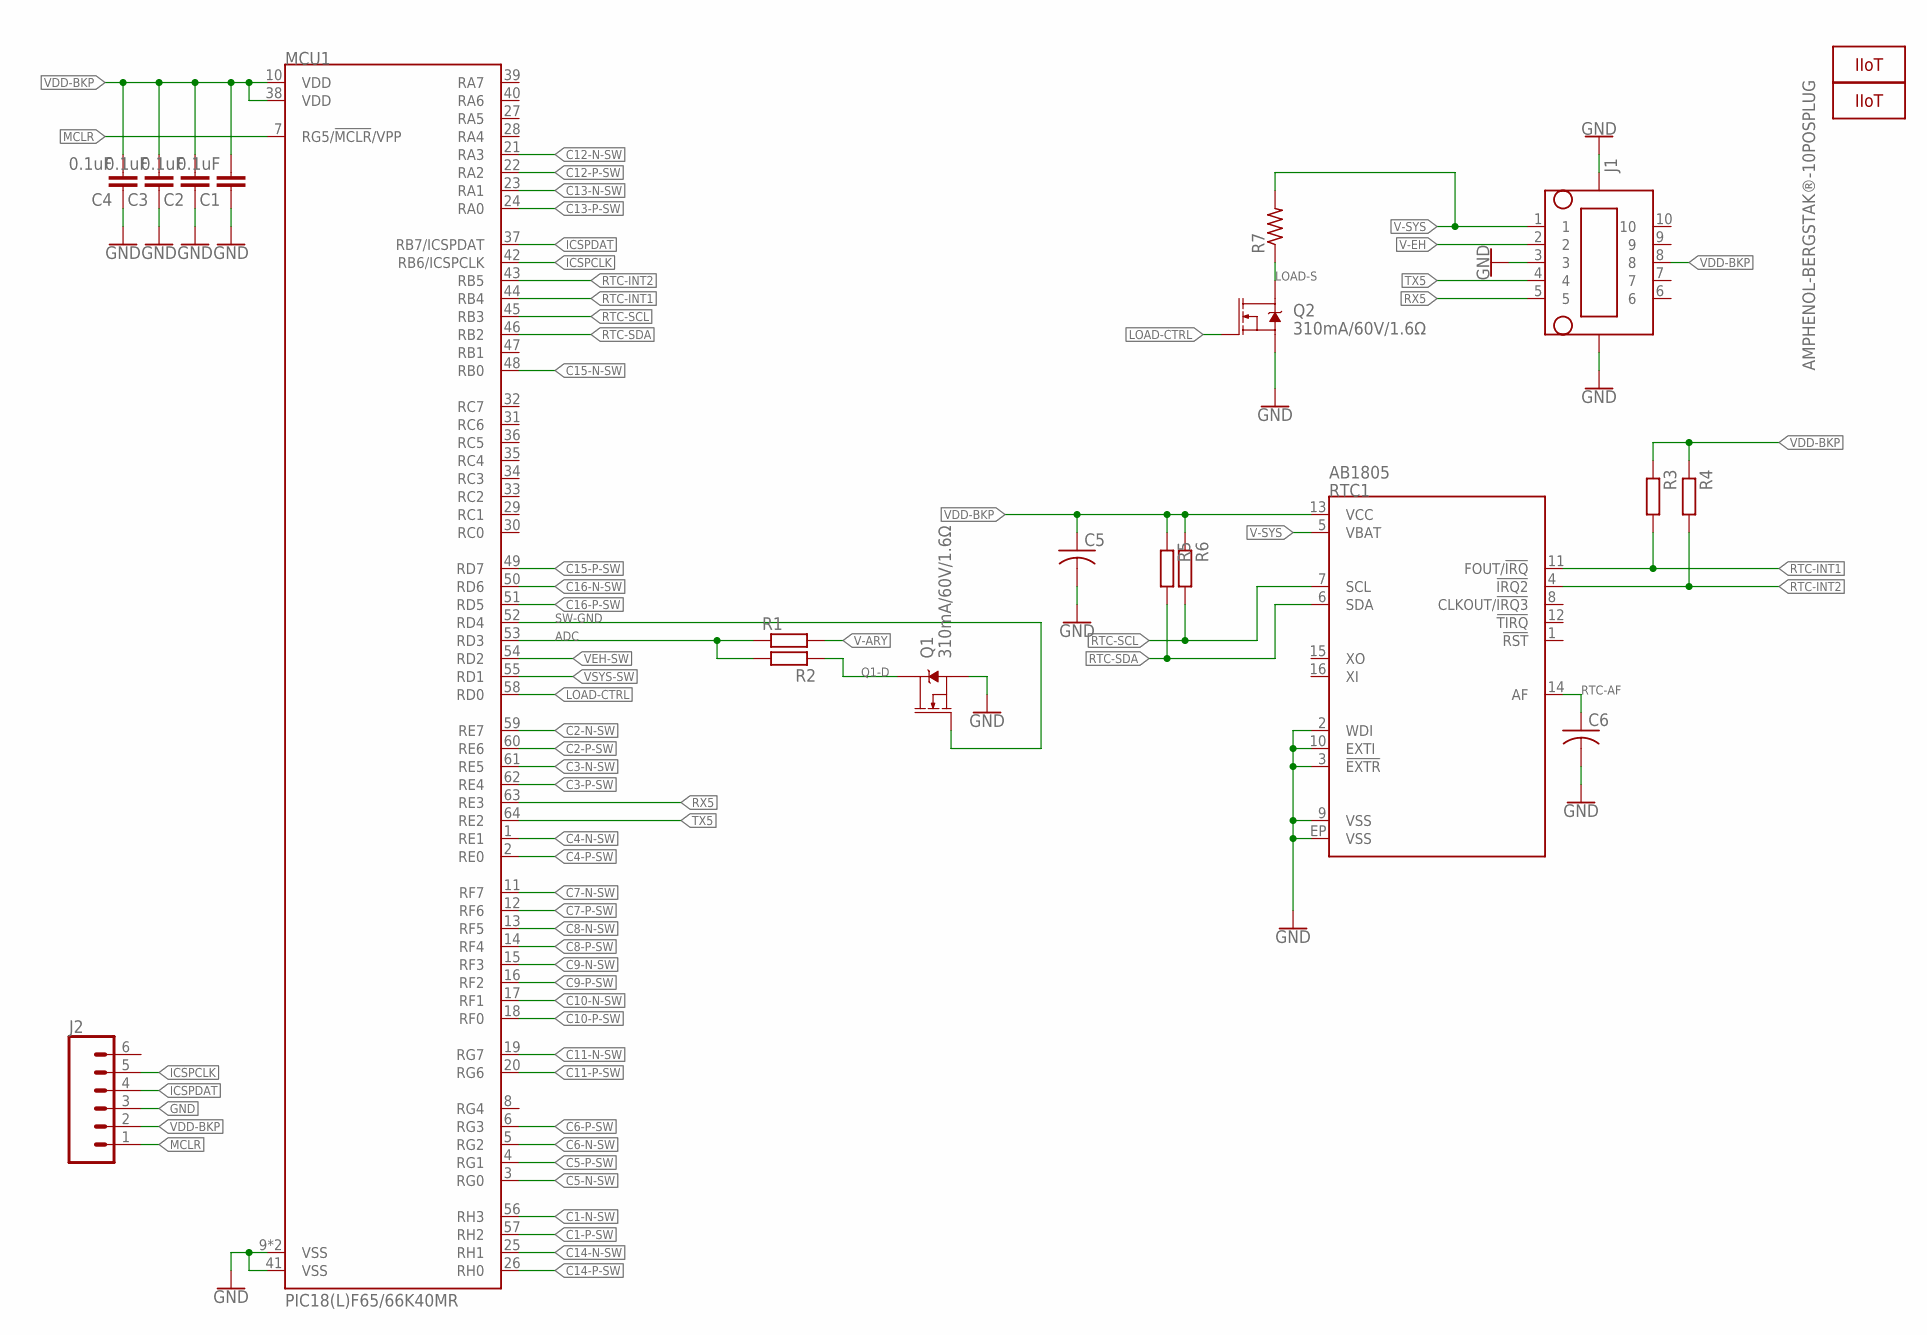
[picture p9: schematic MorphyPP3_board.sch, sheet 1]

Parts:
C1, C2, C3, C4: 0.1uF; 0603
C5, C6: C-USC0402; C0402
J1: AMPHENOL-BERGSTAK®-10POSPLUG; 10132797-10POS-PLUG
J2: CONN_06NO_SILK_NO_POP; 1X06_NO_SILK
LOGO1, LOGO2: IIOT
MCU1: PIC18(L)F65/66K40MR; QFN50P900X900X100-65T715N
Q1, Q2: 310mA/60V/1.6Ω; SOT323
R1, R2, R3, R4, R5, R6: R-EU_R0402; R0402
R7: R-US_R0805; R0805
RTC1: AB1805; QFN-16-3X3

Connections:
ADC: MCU1.53 (RD3), R1.1, R2.2
C1-N-SW: MCU1.56 (RH3); also elsewhere on the board
C1-P-SW: MCU1.57 (RH2); also elsewhere on the board
C2-N-SW: MCU1.59 (RE7); also elsewhere on the board
C2-P-SW: MCU1.60 (RE6); also elsewhere on the board
C3-N-SW: MCU1.61 (RE5); also elsewhere on the board
C3-P-SW: MCU1.62 (RE4); also elsewhere on the board
C4-N-SW: MCU1.1 (RE1); also elsewhere on the board
C4-P-SW: MCU1.2 (RE0); also elsewhere on the board
C5-N-SW: MCU1.3 (RG0); also elsewhere on the board
C5-P-SW: MCU1.4 (RG1); also elsewhere on the board
C6-N-SW: MCU1.5 (RG2); also elsewhere on the board
C6-P-SW: MCU1.6 (RG3); also elsewhere on the board
C7-N-SW: MCU1.11 (RF7); also elsewhere on the board
C7-P-SW: MCU1.12 (RF6); also elsewhere on the board
C8-N-SW: MCU1.13 (RF5); also elsewhere on the board
C8-P-SW: MCU1.14 (RF4); also elsewhere on the board
C9-N-SW: MCU1.15 (RF3); also elsewhere on the board
C9-P-SW: MCU1.16 (RF2); also elsewhere on the board
C10-N-SW: MCU1.17 (RF1); also elsewhere on the board
C10-P-SW: MCU1.18 (RF0); also elsewhere on the board
C11-N-SW: MCU1.19 (RG7); also elsewhere on the board
C11-P-SW: MCU1.20 (RG6); also elsewhere on the board
C12-N-SW: MCU1.21 (RA3); also elsewhere on the board
C12-P-SW: MCU1.22 (RA2); also elsewhere on the board
C13-N-SW: MCU1.23 (RA1); also elsewhere on the board
C13-P-SW: MCU1.24 (RA0); also elsewhere on the board
C14-N-SW: MCU1.25 (RH1); also elsewhere on the board
C14-P-SW: MCU1.26 (RH0); also elsewhere on the board
C15-N-SW: MCU1.48 (RB0); also elsewhere on the board
C15-P-SW: MCU1.49 (RD7); also elsewhere on the board
C16-N-SW: MCU1.50 (RD6); also elsewhere on the board
C16-P-SW: MCU1.51 (RD5); also elsewhere on the board
GND: C1.1, C2.1, C3.1, C4.1, C5.2, C6.2, J1.3, J1.MNT1, J1.MNT2, J2.3, MCU1.9 (VSS), MCU1.41 (VSS), MCU1.65 (VSS), Q1.2 (S), Q2.2 (S), RTC1.2 (WDI), RTC1.3 (!EXTR), RTC1.9 (VSS), RTC1.10 (EXTI), RTC1.EP (VSS); also elsewhere on the board
ICSPCLK: J2.5, MCU1.42 (RB6/ICSPCLK)
ICSPDAT: J2.4, MCU1.37 (RB7/ICSPDAT)
LOAD-CTRL: MCU1.58 (RD0), Q2.1 (G)
LOAD-S: Q2.3 (D), R7.1
MCLR: J2.1, MCU1.7 (RG5/!MCLR!/VPP)
Q1-D: Q1.3 (D), R2.1
RTC-AF: C6.1, RTC1.14 (AF)
RTC-INT1: MCU1.44 (RB4), R3.2, RTC1.11 (FOUT/!IRQ)
RTC-INT2: MCU1.43 (RB5), R4.2, RTC1.4 (!IRQ2)
RTC-SCL: MCU1.45 (RB3), R6.2, RTC1.7 (SCL)
RTC-SDA: MCU1.46 (RB2), R5.2, RTC1.6 (SDA)
RX5: J1.5, MCU1.63 (RE3)
SW-GND: MCU1.52 (RD4), Q1.1 (G)
TX5: J1.4, MCU1.64 (RE2)
V-ARY: R1.2; also elsewhere on the board
V-EH: J1.2; also elsewhere on the board
V-SYS: J1.1, R7.2, RTC1.5 (VBAT); also elsewhere on the board
VDD-BKP: C1.2, C2.2, C3.2, C4.2, C5.1, J1.8, J2.2, MCU1.10 (VDD), MCU1.38 (VDD), R3.1, R4.1, R5.1, R6.1, RTC1.13 (VCC); also elsewhere on the board
VEH-SW: MCU1.54 (RD2); also elsewhere on the board
VSYS-SW: MCU1.55 (RD1); also elsewhere on the board

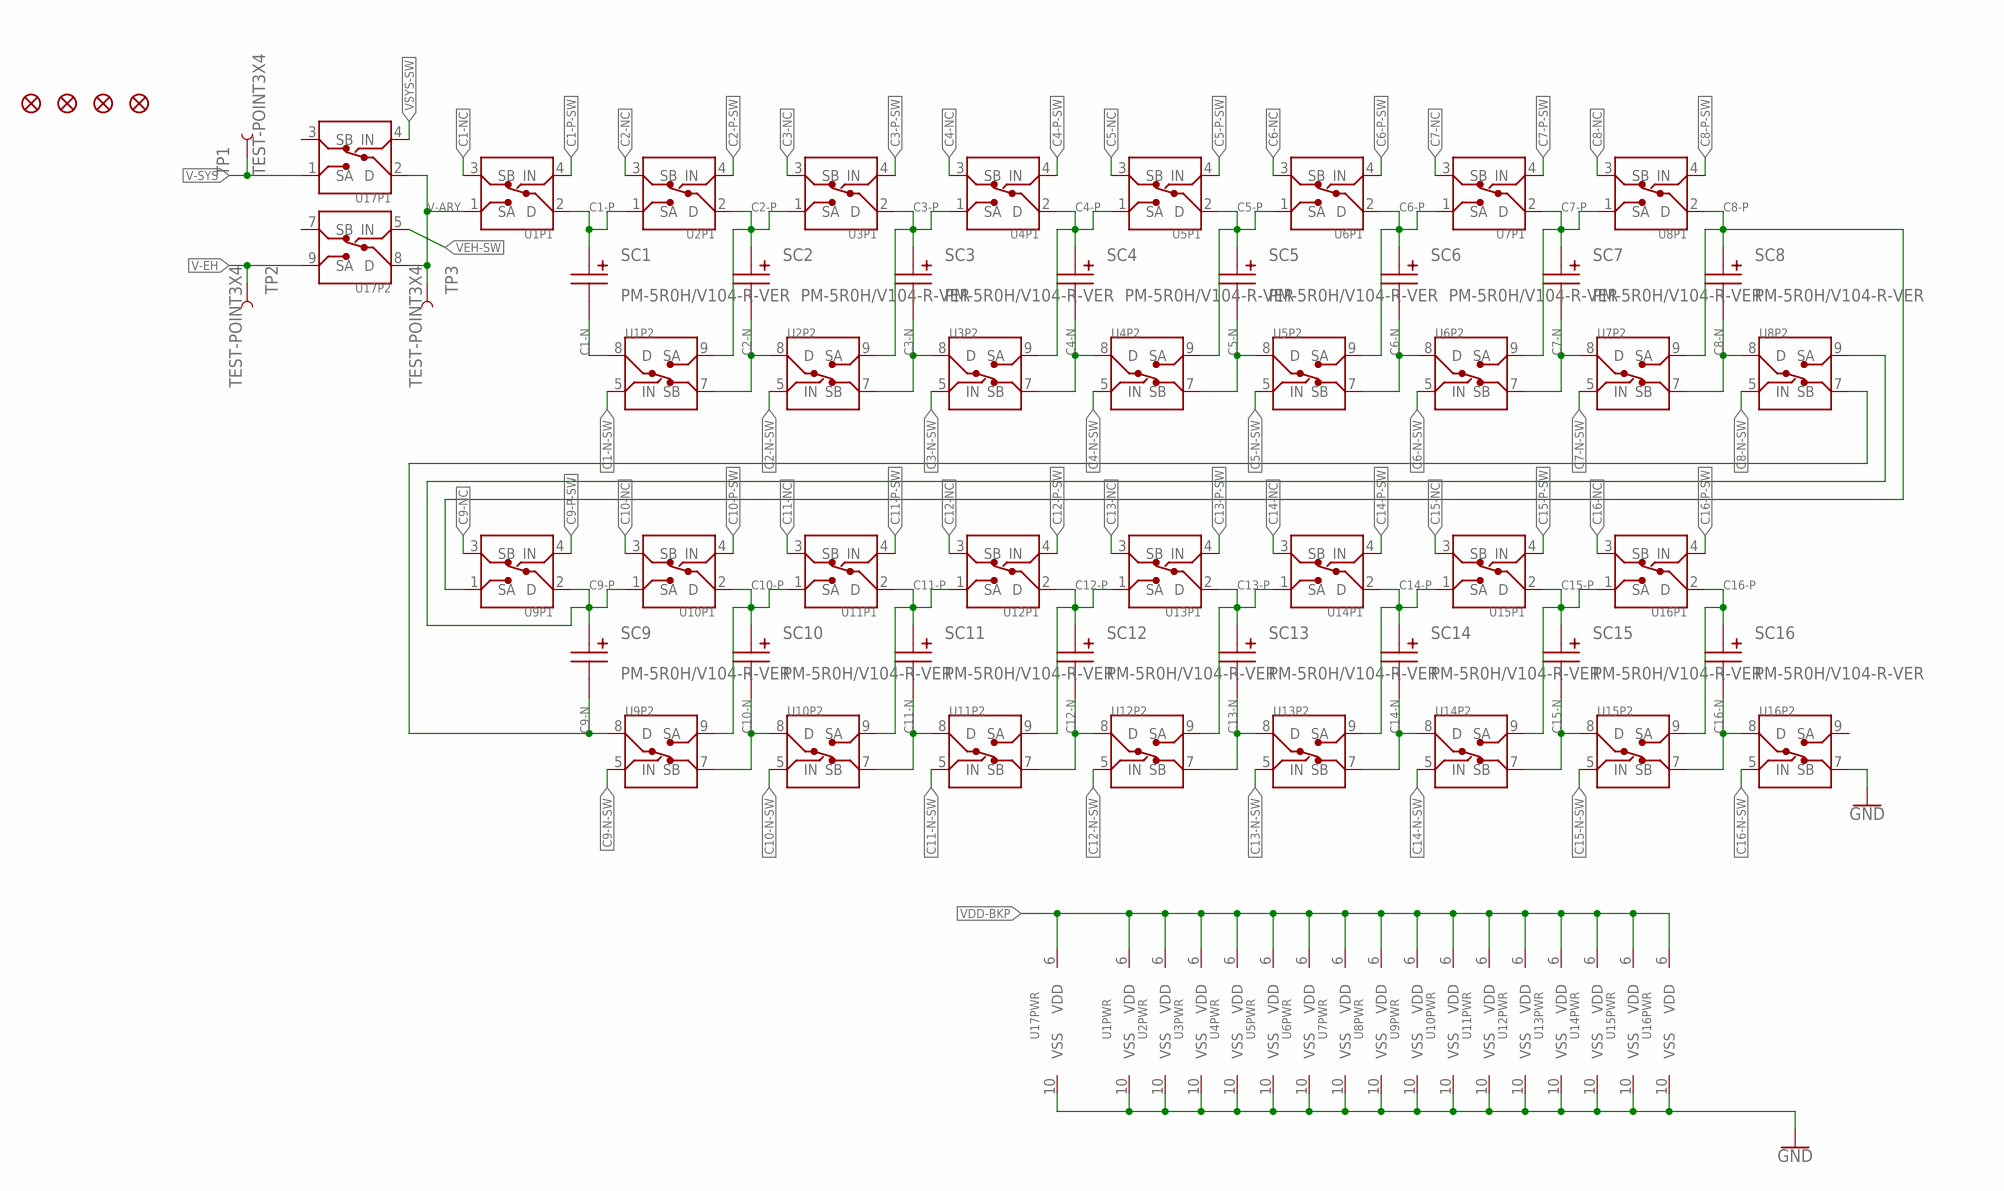
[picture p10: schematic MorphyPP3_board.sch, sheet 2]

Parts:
FD1, FD2, FD3, FD4: FIDUCIAL1X2; FIDUCIAL-1X2
SC1, SC2, SC3, SC4, SC5, SC6, SC7, SC8, SC9, SC10, SC11, SC12, SC13, SC14, SC15, SC16: PM-5R0H/V104-R-VER; EATON-13X11.3X6-V
TP1, TP2, TP3: TEST-POINT3X4; PAD.03X.04
U1, U2, U3, U4, U5, U6, U7, U8, U9, U10, U11, U12, U13, U14, U15, U16, U17: ADG824; CP-10-10

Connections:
C1-N: SC1.N, U1.8 (D)
C1-N-SW: U1.5 (IN); also elsewhere on the board
C1-NC: U1.3 (SB)
C1-P: SC1.P, U1.2 (D), U2.1 (SA)
C1-P-SW: U1.4 (IN); also elsewhere on the board
C2-N: SC2.N, U1.7 (SB), U2.8 (D)
C2-N-SW: U2.5 (IN); also elsewhere on the board
C2-NC: U2.3 (SB)
C2-P: SC2.P, U1.9 (SA), U2.2 (D), U3.1 (SA)
C2-P-SW: U2.4 (IN); also elsewhere on the board
C3-N: SC3.N, U2.7 (SB), U3.8 (D)
C3-N-SW: U3.5 (IN); also elsewhere on the board
C3-NC: U3.3 (SB)
C3-P: SC3.P, U2.9 (SA), U3.2 (D), U4.1 (SA)
C3-P-SW: U3.4 (IN); also elsewhere on the board
C4-N: SC4.N, U3.7 (SB), U4.8 (D)
C4-N-SW: U4.5 (IN); also elsewhere on the board
C4-NC: U4.3 (SB)
C4-P: SC4.P, U3.9 (SA), U4.2 (D), U5.1 (SA)
C4-P-SW: U4.4 (IN); also elsewhere on the board
C5-N: SC5.N, U4.7 (SB), U5.8 (D)
C5-N-SW: U5.5 (IN); also elsewhere on the board
C5-NC: U5.3 (SB)
C5-P: SC5.P, U4.9 (SA), U5.2 (D), U6.1 (SA)
C5-P-SW: U5.4 (IN); also elsewhere on the board
C6-N: SC6.N, U5.7 (SB), U6.8 (D)
C6-N-SW: U6.5 (IN); also elsewhere on the board
C6-NC: U6.3 (SB)
C6-P: SC6.P, U5.9 (SA), U6.2 (D), U7.1 (SA)
C6-P-SW: U6.4 (IN); also elsewhere on the board
C7-N: SC7.N, U6.7 (SB), U7.8 (D)
C7-N-SW: U7.5 (IN); also elsewhere on the board
C7-NC: U7.3 (SB)
C7-P: SC7.P, U6.9 (SA), U7.2 (D), U8.1 (SA)
C7-P-SW: U7.4 (IN); also elsewhere on the board
C8-N: SC8.N, U7.7 (SB), U8.8 (D)
C8-N-SW: U8.5 (IN); also elsewhere on the board
C8-NC: U8.3 (SB)
C8-P: SC8.P, U7.9 (SA), U8.2 (D), U9.1 (SA)
C8-P-SW: U8.4 (IN); also elsewhere on the board
C9-N: SC9.N, U8.7 (SB), U9.8 (D)
C9-N-SW: U9.5 (IN); also elsewhere on the board
C9-NC: U9.3 (SB)
C9-P: SC9.P, U8.9 (SA), U9.2 (D), U10.1 (SA)
C9-P-SW: U9.4 (IN); also elsewhere on the board
C10-N: SC10.N, U9.7 (SB), U10.8 (D)
C10-N-SW: U10.5 (IN); also elsewhere on the board
C10-NC: U10.3 (SB)
C10-P: SC10.P, U9.9 (SA), U10.2 (D), U11.1 (SA)
C10-P-SW: U10.4 (IN); also elsewhere on the board
C11-N: SC11.N, U10.7 (SB), U11.8 (D)
C11-N-SW: U11.5 (IN); also elsewhere on the board
C11-NC: U11.3 (SB)
C11-P: SC11.P, U10.9 (SA), U11.2 (D), U12.1 (SA)
C11-P-SW: U11.4 (IN); also elsewhere on the board
C12-N: SC12.N, U11.7 (SB), U12.8 (D)
C12-N-SW: U12.5 (IN); also elsewhere on the board
C12-NC: U12.3 (SB)
C12-P: SC12.P, U11.9 (SA), U12.2 (D), U13.1 (SA)
C12-P-SW: U12.4 (IN); also elsewhere on the board
C13-N: SC13.N, U12.7 (SB), U13.8 (D)
C13-N-SW: U13.5 (IN); also elsewhere on the board
C13-NC: U13.3 (SB)
C13-P: SC13.P, U12.9 (SA), U13.2 (D), U14.1 (SA)
C13-P-SW: U13.4 (IN); also elsewhere on the board
C14-N: SC14.N, U13.7 (SB), U14.8 (D)
C14-N-SW: U14.5 (IN); also elsewhere on the board
C14-NC: U14.3 (SB)
C14-P: SC14.P, U13.9 (SA), U14.2 (D), U15.1 (SA)
C14-P-SW: U14.4 (IN); also elsewhere on the board
C15-N: SC15.N, U14.7 (SB), U15.8 (D)
C15-N-SW: U15.5 (IN); also elsewhere on the board
C15-NC: U15.3 (SB)
C15-P: SC15.P, U14.9 (SA), U15.2 (D), U16.1 (SA)
C15-P-SW: U15.4 (IN); also elsewhere on the board
C16-N: SC16.N, U15.7 (SB), U16.8 (D)
C16-N-SW: U16.5 (IN); also elsewhere on the board
C16-NC: U16.3 (SB)
C16-P: SC16.P, U15.9 (SA), U16.2 (D)
C16-P-SW: U16.4 (IN); also elsewhere on the board
GND: U1.10 (VSS), U2.10 (VSS), U3.10 (VSS), U4.10 (VSS), U5.10 (VSS), U6.10 (VSS), U7.10 (VSS), U8.10 (VSS), U9.10 (VSS), U10.10 (VSS), U11.10 (VSS), U12.10 (VSS), U13.10 (VSS), U14.10 (VSS), U15.10 (VSS), U16.7 (SB), U16.10 (VSS), U17.10 (VSS); also elsewhere on the board
V-ARY: TP3.P$1, U1.1 (SA), U17.2 (D), U17.8 (D); also elsewhere on the board
V-EH: TP2.P$1, U17.9 (SA); also elsewhere on the board
V-SYS: TP1.P$1, U17.1 (SA); also elsewhere on the board
VDD-BKP: U1.6 (VDD), U2.6 (VDD), U3.6 (VDD), U4.6 (VDD), U5.6 (VDD), U6.6 (VDD), U7.6 (VDD), U8.6 (VDD), U9.6 (VDD), U10.6 (VDD), U11.6 (VDD), U12.6 (VDD), U13.6 (VDD), U14.6 (VDD), U15.6 (VDD), U16.6 (VDD), U17.6 (VDD); also elsewhere on the board
VEH-SW: U17.5 (IN); also elsewhere on the board
VSYS-SW: U17.4 (IN); also elsewhere on the board

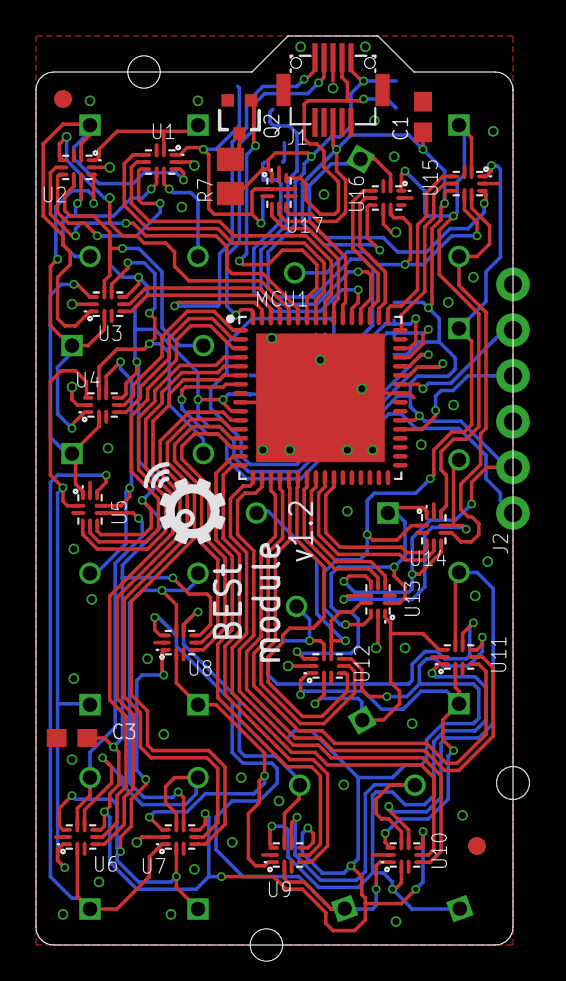
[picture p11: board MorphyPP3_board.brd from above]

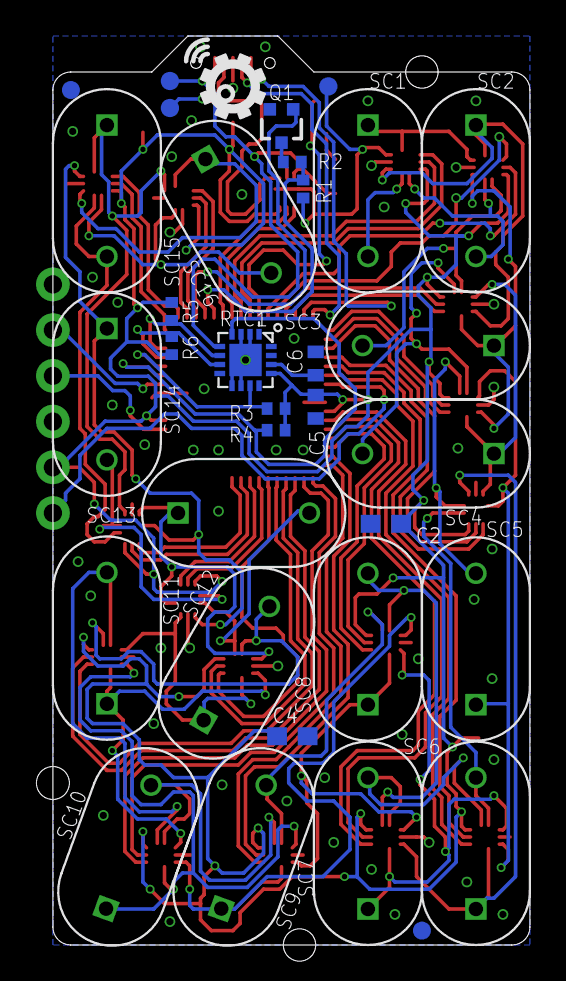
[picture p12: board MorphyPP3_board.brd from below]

Board: 2 copper layers, 26.5 x 50.5 mm, 61 parts (34 on the bottom side), 86 nets.

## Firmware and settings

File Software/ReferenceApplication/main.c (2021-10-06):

/**
 * Copyright (c) 2017 - 2020, Nordic Semiconductor ASA
 *
 * All rights reserved.
 *
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
 * 3. Neither the name of Nordic Semiconductor ASA nor the names of its
 *    contributors may be used to endorse or promote products derived from this
 *    software without specific prior written permission.
 *
 * 4. This software, with or without modification, must only be used with a
 *    Nordic Semiconductor ASA integrated circuit.
 *
 * 5. Any software provided in binary form under this license must not be reverse
 *    engineered, decompiled, modified and/or disassembled.
 *
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
 */
/* 
 * File name  : main.c
 * Author     : KU Leuven
 * Description: This file provides a sample implementation for the morphy module
 * and shows how the application can communicate with the morphy module
 */

#include <stdint.h>
#include <string.h>
#include "nordic_common.h"
#include "nrf.h"
#include "app_error.h"

#include "app_timer.h"
#include "peer_manager.h"
#include "peer_manager_handler.h"
#include "bsp_btn_ble.h"
#include "FreeRTOS.h"
#include "task.h"
#include "timers.h"
#include "semphr.h"
#include "fds.h"
#include "ble_conn_state.h"
#include "nrf_drv_clock.h"
#include "app_uart.h"
#include "app_error.h"
#if defined (UART_PRESENT)
#include "nrf_uart.h"
#endif
#if defined (UARTE_PRESENT)
#include "nrf_uarte.h"
#endif
#include "nrf_drv_gpiote.h"
#include "morphy.h"

#include "nrf_log.h"
#include "nrf_log_ctrl.h"
#include "nrf_log_default_backends.h"


#if NRF_LOG_ENABLED
static TaskHandle_t m_logger_thread;                                /**< Definition of Logger thread. */
#endif
static TaskHandle_t m_morphy_thread;
static TaskHandle_t m_app_thread;

/**@brief Function for initializing the nrf log module.
 */
static void log_init(void)
{
    ret_code_t err_code = NRF_LOG_INIT(NULL);
    APP_ERROR_CHECK(err_code);

    NRF_LOG_DEFAULT_BACKENDS_INIT();
}


#if NRF_LOG_ENABLED
/**@brief Thread for handling the logger.
 *
 * @details This thread is responsible for processing log entries if logs are deferred.
 *          Thread flushes all log entries and suspends. It is resumed by idle task hook.
 *
 * @param[in]   arg   Pointer used for passing some arbitrary information (context) from the
 *                    osThreadCreate() call to the thread.
 */
static void logger_thread(void * arg)
{
    UNUSED_PARAMETER(arg);

    while (1)
    {
        NRF_LOG_FLUSH();

        vTaskSuspend(NULL); // Suspend myself
    }
}
#endif //NRF_LOG_ENABLED

/**@brief A function which is hooked to idle task.
 * @note Idle hook must be enabled in FreeRTOS configuration (configUSE_IDLE_HOOK).
 */
void vApplicationIdleHook( void )
{
#if NRF_LOG_ENABLED
     vTaskResume(m_logger_thread);
#endif
}

#ifdef FPU_INTERRUPT_MODE
void FPU_IRQHandler(void)
{
    // Prepare pointer to stack address with pushed FPSCR register.
    uint32_t * fpscr = (uint32_t * )(FPU->FPCAR + FPU_FPSCR_REG_STACK_OFF);
    // Execute FPU instruction to activate lazy stacking.
    (void)__get_FPSCR();
    // Clear flags in stacked FPSCR register.
    *fpscr = *fpscr & ~(FPU_EXCEPTION_MASK);
}
#endif

/**@brief Function for initializing the clock.
 */
static void clock_init(void)
{
    ret_code_t err_code = nrf_drv_clock_init();
    APP_ERROR_CHECK(err_code);
}


#define RX_PIN_NUMBER  8
#define TX_PIN_NUMBER  6
#define CTS_PIN_NUMBER 7
#define RTS_PIN_NUMBER 5
#define UART_RX_PIN              NRF_GPIO_PIN_MAP(1,1)    // UART RX pin number.
#define UART_TX_PIN              NRF_GPIO_PIN_MAP(1,2)    // UART TX pin number.
#define UART_CTS_PIN             NRF_GPIO_PIN_MAP(0,7)     // UART Clear To Send pin number.
#define UART_RTS_PIN             NRF_GPIO_PIN_MAP(0,9)    // UART Request To Send pin number.
#define UART_TX_BUF_SIZE 256                         /**< UART TX buffer size. */
#define UART_RX_BUF_SIZE 256                         /**< UART RX buffer size. */
volatile bool data_available = false;
static uint8_t data_array[200];
static uint8_t data_length = 0;
static bool ledToggle = false;
volatile bool lowVoltageAlarm = false;
volatile bool startTasks = false;

#define LV_ALARM_PIN            NRF_GPIO_PIN_MAP(0,27)
#define TASK_GPIO               NRF_GPIO_PIN_MAP(1,10)

void uart_error_handle(app_uart_evt_t * p_event)
{
    static uint8_t index;
    
    if (p_event->evt_type == APP_UART_COMMUNICATION_ERROR)
    {
        APP_ERROR_HANDLER(p_event->data.error_communication);
    }
    else if (p_event->evt_type == APP_UART_FIFO_ERROR)
    {
        APP_ERROR_HANDLER(p_event->data.error_code);
    }
    else if (p_event->evt_type == APP_UART_DATA_READY)
    {  
       UNUSED_VARIABLE(app_uart_get(&data_array[index]));
       index++;
       
       //NRF_LOG_INFO("received: %s", );
       //NRF_LOG_RAW_INFO("%s\r\n", data_array);
       /* TODO: Substitute '\n' in the statement below with the Modbus escape character, if 
           applicable */
       uint8_t qbuf[3] = {0}, recv = 0;
       if ((data_array[index - 1] == '\n'))
       {
            qbuf[0] = data_array[0]; qbuf[1] = data_array[1]; recv = atoi(qbuf);
            if (recv == 18) {
                morphyCallBrownoutHandler();
            }
            else if (recv == 19) {
                morphyCallBugHandler(data_array, index);
            }
            //else if (recv == 20) {
            //    //vTaskStartScheduler();
            //    startTasks = true;
            //}
            else {
                data_available = true;
                data_length = index;
                NRF_LOG_INFO("Received command copying");

                index = 0;
            }
        }

    }
}

void in_pin_handler(nrf_drv_gpiote_pin_t pin, nrf_gpiote_polarity_t action)
{
    lowVoltageAlarm = true;
    morphyCallBrownoutHandler();
}

static void gpio_init(void)
{
    ret_code_t err_code;

    err_code = nrf_drv_gpiote_init();
    APP_ERROR_CHECK(err_code);

    //nrf_drv_gpiote_out_config_t out_config = GPIOTE_CONFIG_OUT_SIMPLE(false);

    //err_code = nrf_drv_gpiote_out_init(TASK_GPIO, &out_config);
    //APP_ERROR_CHECK(err_code);

    nrf_drv_gpiote_in_config_t in_config = GPIOTE_CONFIG_IN_SENSE_TOGGLE(true);
    //nrf_drv_gpiote_in_config_t in_config = GPIOTE_CONFIG_IN_SENSE_LOTOHI(true);
    in_config.sense = NRF_GPIOTE_POLARITY_LOTOHI;//NRF_GPIOTE_POLARITY_TOGGLE; //NRF_GPIOTE_POLARITY_LOTOHI
    in_config.pull = NRF_GPIO_PIN_PULLDOWN;
    in_config.hi_accuracy = false;
    in_config.is_watcher = false;

    err_code = nrf_drv_gpiote_in_init(LV_ALARM_PIN, &in_config, in_pin_handler);
    APP_ERROR_CHECK(err_code);

    nrf_drv_gpiote_in_event_enable(LV_ALARM_PIN, true);

    nrf_gpio_cfg_output(TASK_GPIO);
    nrf_gpio_pin_clear(TASK_GPIO);
}

#define UART_TEST 1
void uart_init()
{
    uint32_t err_code;

    const app_uart_comm_params_t comm_params =
      {
#ifdef UART_TEST
            RX_PIN_NUMBER,
            TX_PIN_NUMBER,
#else
            UART_RX_PIN,
            UART_TX_PIN,
#endif
            RTS_PIN_NUMBER,
            CTS_PIN_NUMBER,
            APP_UART_FLOW_CONTROL_DISABLED,
            false,
#ifdef UART_TEST
            NRF_UARTE_BAUDRATE_115200
#else
            NRF_UART_BAUDRATE_9600
#endif
      };

    APP_UART_FIFO_INIT(&comm_params,
                         UART_RX_BUF_SIZE,
                         UART_TX_BUF_SIZE,
                         uart_error_handle,
                         APP_IRQ_PRIORITY_HIGHEST,//APP_IRQ_PRIORITY_MID,//APP_IRQ_PRIORITY_LOWEST,
                         err_code);

    APP_ERROR_CHECK(err_code);
}

static uint8_t reconf = 1;
static bool paraConf = true;
static void morphy_app_thread(void * arg)
{
    UNUSED_PARAMETER(arg);
    uint8_t cr;
    float tcorev = 0.0;
    uint16_t corev = 0;

    NRF_LOG_INFO("Starting Morphy App");
    NRF_LOG_INFO("Configuring Morphy");
    
    vTaskDelay(pdMS_TO_TICKS(1000));
    tcorev = getCoreVoltage();
    corev = tcorev * 1000;
    NRF_LOG_INFO("%d\r\n", corev);
    vTaskDelay(pdMS_TO_TICKS(1000));
    tcorev = 2.0;
    setLowVoltageAlarm(tcorev);
    vTaskDelay(pdMS_TO_TICKS(1000));
    NRF_LOG_INFO("Low Voltage Alarm Set\r\n");

    //nrf_drv_gpiote_out_toggle(TASK_GPIO);

    while (1)
    {
        NRF_LOG_INFO("Running App");
        reconfigCapArray(reconf, paraConf);
        reconf++;
        if (reconf > 4) {
            reconf = 1;
        }
        nrf_gpio_pin_toggle(TASK_GPIO);
        //vTaskDelay(pdMS_TO_TICKS(10));
        if (lowVoltageAlarm == true) {
            lowVoltageAlarm = false;
            NRF_LOG_INFO("Low Voltage Detected\r\n");
        }

        vTaskDelay(pdMS_TO_TICKS(10000));
    }
}

static void app_thread(void * arg)
{
    UNUSED_PARAMETER(arg);

    while (1)
    {
        NRF_LOG_INFO("Running App");
        nrf_gpio_pin_toggle(TASK_GPIO);
        vTaskDelay(pdMS_TO_TICKS(1000));
        nrf_gpio_pin_toggle(TASK_GPIO);
        vTaskDelay(pdMS_TO_TICKS(10000));
    }
}


bool uart_tx_data(uint8_t *buf, uint8_t dataSize)
{
    for (uint8_t i = 0; i < dataSize; i++) {
        while (app_uart_put(buf[i]) != NRF_SUCCESS);
    }
    return true;
}

bool uart_rx_data(uint8_t *buf, uint8_t *dataSize)
{
    if (buf == NULL) {
        return false;
    }

    while (!data_available);
    data_available = false;
    memcpy(buf, data_array, data_length);
    *dataSize = data_length;

    return true;
}

#define CHARGE_LEVEL_MEAS_INTERVAL         2000
static TimerHandle_t m_charge_timer;


void charge_monitor_timer(void)
{
    // Initialize timer module.
    ret_code_t err_code = app_timer_init();
    APP_ERROR_CHECK(err_code);

    // Create timers.
    m_charge_timer = xTimerCreate("CHARGE",
                                   CHARGE_LEVEL_MEAS_INTERVAL,
                                   pdTRUE,
                                   NULL,
                                   charge_level_meas_timeout_handler);

    /* Error checking */
    if(NULL == m_charge_timer)
    {
        APP_ERROR_HANDLER(NRF_ERROR_NO_MEM);
    }
}

/**@brief Function for application main entry.
 */
int main(void)
{
    bool erase_bonds;
    uint32_t err_code;

    bsp_board_init(BSP_INIT_LEDS);

    // Initialize modules.
    log_init();
    clock_init();
    gpio_init();
    uart_init();
    //initMorphy();

#ifdef FPU_INTERRUPT_MODE
    // Enable FPU interrupt
    NVIC_SetPriority(FPU_IRQn, APP_IRQ_PRIORITY_LOWEST);
    NVIC_ClearPendingIRQ(FPU_IRQn);
    NVIC_EnableIRQ(FPU_IRQn);
#endif

    // Do not start any interrupt that uses system functions before system initialisation.
    // The best solution is to start the OS before any other initalisation.

#if NRF_LOG_ENABLED
    // Start execution.
    if (pdPASS != xTaskCreate(logger_thread, "LOGGER", 256, NULL, 1, 0, &m_logger_thread))
    {
        APP_ERROR_HANDLER(NRF_ERROR_NO_MEM);
    }
#endif


    if (pdPASS != xTaskCreate(morphy_app_thread, "Morphy", 256, NULL, 1, 10, &m_morphy_thread))
    {
        APP_ERROR_HANDLER(NRF_ERROR_NO_MEM);
    }

    if (pdPASS != xTaskCreate(app_thread, "app1", 256, NULL, 1, 10, &m_app_thread))
    {
        APP_ERROR_HANDLER(NRF_ERROR_NO_MEM);
    }

    NRF_LOG_INFO("Morphy FreeRTOS example started.");
    // Start FreeRTOS scheduler.
    vTaskStartScheduler();

    for (;;)
    {
        APP_ERROR_HANDLER(NRF_ERROR_FORBIDDEN);
    }
}

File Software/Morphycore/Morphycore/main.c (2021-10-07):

/*
 * File name  : main.c
 * Author     : KU Leuven
 *
 * Description: This file implements morphy's core functionalities: fast charging,
 * delayed brown-out, charge isolation and communication with the application via uart
 * for application task management
 *
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
 * THE SOFTWARE IS PROVIDED "AS IS", WITHOUT WARRANTY OF ANY KIND, EXPRESS OR
 * IMPLIED, INCLUDING BUT NOT LIMITED TO THE WARRANTIES OF MERCHANTABILITY, FITNESS
 * FOR A PARTICULAR PURPOSE AND NONINFRINGEMENT. IN NO EVENT SHALL THE AUTHORS OR
 * COPYRIGHT HOLDERS BE LIABLE FOR ANY CLAIM, DAMAGES OR OTHER LIABILITY, WHETHER
 * IN AN ACTION OF CONTRACT, TORT OR OTHERWISE, ARISING FROM, OUT OF OR IN
 * CONNECTION WITH THE SOFTWARE OR THE USE OR OTHER DEALINGS IN THE SOFTWARE.
 */

#include "mcc_generated_files/mcc.h"
#include<string.h>
#include "ConfigureCaps.h"


#define MAX_COMMAND_LEN 20

char msgOK[] = "0\n";
char command11[] ={0x00,0x31,0x31,0x0A};
char command12[] ={0x31,0x32,0x0A};
char command13[] ={0x31,0x33,0x0A};
char command14[] ={0x31,0x34,0x2C,0x32,0x2E,0x30,0x0A};
char command16[] ={0x31,0x36,0x0A};
char command17[] ={0x31,0x37,0x0A};
char command18[] ={0x31,0x38,0x0A};
char command19[] ={0x31,0x39,0x0A};
char command20[] ={0x00,0x31,0x31,0x0A};

extern volatile uint8_t Flag5sfastcharing; 
extern volatile uint8_t isolatedflag ;
 volatile uint8_t DectecLowVFlag =0;
 float getADCValue(void);
extern void Caps8seriesConnection(void);
extern void fastChargingcaps(void);
extern void isolatedOneTaskCap(void);

/*
                Main application
 */


/* Get sample value from channel_AND3 (GPIO RD3) */
/* ADC 10bit; VCC 3.3V */
float getADCValue(void)   
{
    float ADC_float = 0;
    adc_result_t getADCValue =0 ;
   
    getADCValue= ADCC_GetSingleConversion(channel_AND3);
    
    ADC_float =  getADCValue *(3.3 / 1023);
    return ADC_float;

}

uint8_t* ConvertADCtoSend(float convertedValue01)
{
    char msgValue[8] ;
    sprintf(msgValue,"%.2f" ,convertedValue01);
    return msgValue;
}

void DectecLowVolatge(void)
{
        LowVoltagePin_SetLow();  
        __delay_ms(1);
        LowVoltagePin_SetHigh();    
}


/****************** CMDS ****************
nRF - PIC ++++++++++++++++
11 -> SetMaxVoltage
OK <- 00
12 -> SetMinVoltage
OK <- 00
13 -> getCoreVoltage
<> <- <Current Voltage>
14 -> setLowVoltageAlarm
OK <- 00
//15 -> reconfigCapArray
//OK <- 00
16 -> scheduleInterrupt
OK <- 00
17 -> schedulePowerOn
OK <- 00
18 <- handleBrownOut
OK -> 00
19 <- handlePowerBug
20 -> runTask
OK <- 00
****************************************/



void executeCommand(char *command)
{  
    float ADCValue_float;
    adc_result_t getADCValue1;
    uint8_t* msgValue;
    
    if(strcmp(command, command11) == 0)
    {
        for(uint8_t i = 0; i < strlen(msgOK); i++)
        {
            EUSART5_Write(msgOK[i]);
        } 
    }
    
    if (strcmp(command, command12) == 0)
    {
        for(uint8_t i = 0; i < strlen(msgOK); i++)
        {
            EUSART5_Write(msgOK[i]);
        } 
    } 
    
    if (strcmp(command, command13) == 0)
    {
        ADCValue_float=getADCValue();
        msgValue= ConvertADCtoSend(ADCValue_float);
       
        msgValue[strlen(msgValue)-1] = 0x0A;
        for(uint8_t i = 0; i < strlen(msgValue); i++)
        {
          EUSART5_Write(msgValue[i]);
        }
    }
    
    if (memcmp(command, command14,4)== 0)
    {
        for(uint8_t i = 0; i < strlen(msgOK); i++)
        {
            EUSART5_Write(msgOK[i]);
        } 
        DectecLowVFlag =1;
    }
    
    if (strcmp(command, command16) == 0)
    {
        for(uint8_t i = 0; i < strlen(msgOK); i++)
        {
            EUSART5_Write(msgOK[i]);
        } 
    }
    
    if (strcmp(command, command17) == 0)
    {
        for(uint8_t i = 0; i < strlen(msgOK); i++)
        {
            EUSART5_Write(msgOK[i]);
        } 
    }
    
    if (memcmp(command, command20,3) == 0)
    {
        for(uint8_t i = 0; i < strlen(msgOK); i++)
        {
            EUSART5_Write(msgOK[i]);
        } 
    }
}


void main(void)
{   
    char c;
    char command[MAX_COMMAND_LEN];
    uint8_t index = 0;
 
    // Initialize the device
    SYSTEM_Initialize();
    // If using interrupts in PIC18 High/Low Priority Mode you need to enable the Global High and Low Interrupts
    // If using interrupts in PIC Mid-Range Compatibility Mode you need to enable the Global and Peripheral Interrupts
    // Use the following macros to:

    // Enable the Global Interrupts
    INTERRUPT_GlobalInterruptEnable();

    // Disable the Global Interrupts
    //INTERRUPT_GlobalInterruptDisable();

    // Enable the Peripheral Interrupts
    INTERRUPT_PeripheralInterruptEnable();

    // Disable the Peripheral Interrupts
    //INTERRUPT_PeripheralInterruptDisable();
    isolatedflag=0;
    Flag5sfastcharing=0;
    Caps8seriesConnection();
    
   while (1)
    {
       if((Flag5sfastcharing==1) &&(isolatedflag ==0) )
       {
           fastChargingcaps();
            Flag5sfastcharing =0;
       }
       else if (isolatedflag ==1)
       {
            isolatedOneTaskCap();
             LowVoltagePin_SetLow();   
             while(1)
             {
                   c= EUSART5_Read();
                    if(c != 0x0A)
                    {
                        command[index++] =c;
                    }
                    else if(c == 0x0A)
                    {
                        //EUSART2_Write(c);
                        command[index] = c;
                        command[index+1] = '\0';          
                        index =0;
                        executeCommand(command); 
                    }
                   if(DectecLowVFlag ==1)
                   {
                       delayedBrownOut();
                       if(isolatedflag ==0)
                       {
                           DectecLowVolatge();
                           __delay_ms(100);
                           VSYS_SW_SetLow();                       
                           break;
                       }                      
                   }
           }
       }
       
       
            
//         if(isolatedflag ==1)  // isolated a cap as output
//        {
//            isolatedOneTaskCap();
//            delayedBrownOut();
////            while(1)
////            {
////                  c= EUSART5_Read();
////            // Add your application code
////                if(c != 0x0A)
////                {
////                    command[index++] =c;
////                }
////                else if(c == 0x0A)
////                {
////                    //EUSART2_Write(c);
////                    command[index] = c;
////                    command[index+1] = '\0';          
////                    index =0;
////    //                executeCommand(command); 
////               }       
////            }        
//        }
    }
}

/**
 End of File
*/

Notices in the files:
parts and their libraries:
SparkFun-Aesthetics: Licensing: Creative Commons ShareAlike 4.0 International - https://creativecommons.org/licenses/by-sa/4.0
